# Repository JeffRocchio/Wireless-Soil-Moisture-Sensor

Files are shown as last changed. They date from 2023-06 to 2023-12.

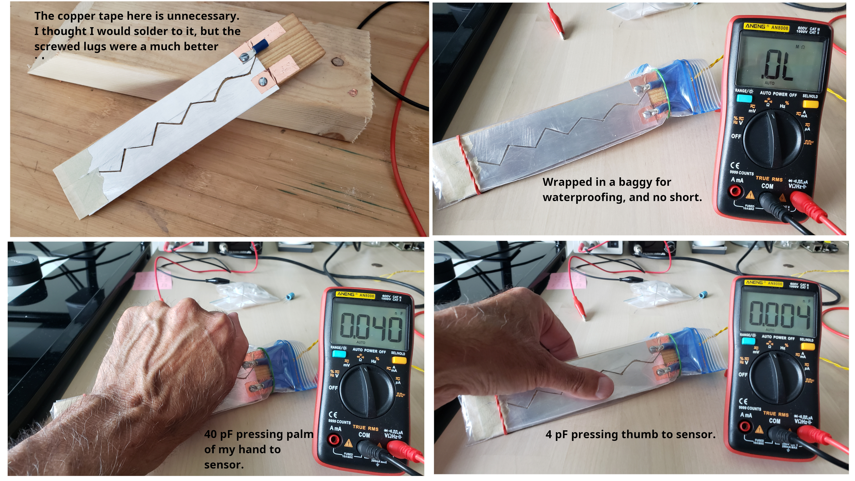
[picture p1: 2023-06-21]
ProjectLog/MS10_b_Sensor-design.jpg

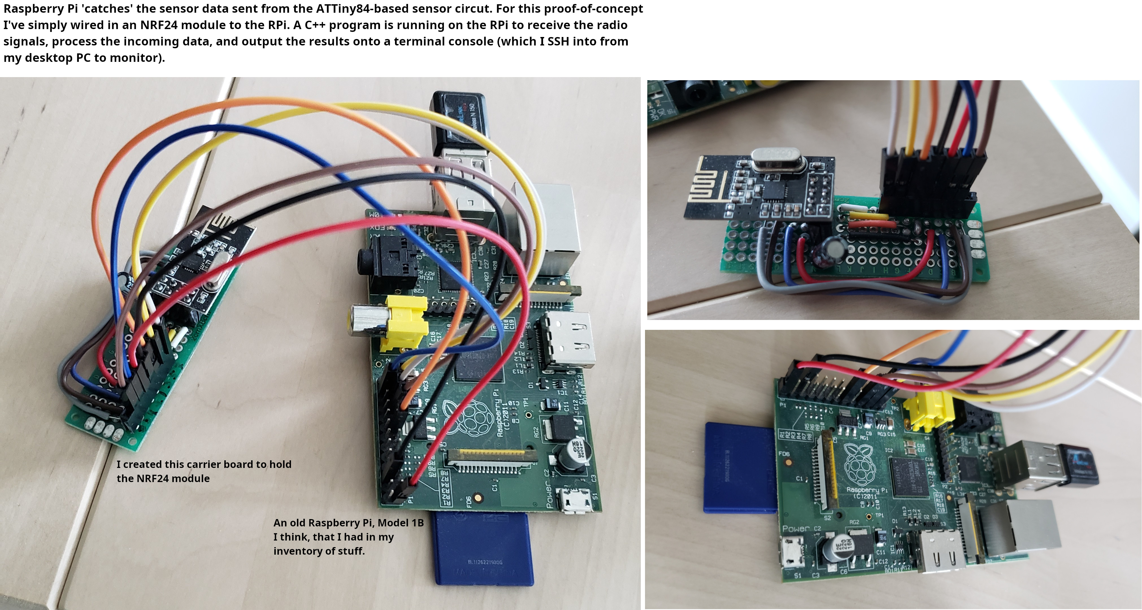
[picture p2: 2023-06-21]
Physical-Construction/ReceivingServer/Receiver-server_Raspberry-Pi-with-NRF24.jpg

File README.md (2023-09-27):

# Description

Wireless soil moisture sensor using capacitance as the sensing mechanism.

This is a DIY project for use in my own garden, and if it works out, my neighboorhood's community garden.

For the initial proof of concept I am making just one sensor device, which wirelessly sends its sensor data over to a Raspberry Pi for processing and display onto a terminal session (which I SSH into from my desktop PC). If the proof of concept works then I would have the Raspberry Pi post the data to a web page.

This project uses an ATTiny84 MCU and two NRF24 radio modules along with the Raspberry Pi.

The folder ProjectLog contains detailed notes on all the trials, tribulations, and successes as I go. Those log entries also contain key references - such as the Arduino core used for the ATTiny84 and the github repo for the NRF24 libraries.

# Status

**9/27/2023**: I have nearly completed work on *[Milestone #12](https://github.com/JeffRocchio/Wireless-Soil-Moisture-Sensor/blob/main/ProjectLog/MS12_a_Notes_Conversational-Software.pdf)*: Redesigning the ATTiny84 and Raspberry Pi software to be 'Event-Driven,' 'Non-Blocking,' and conversational. The only missing piece is the ability of the ATTiny to handle a command coming back from the RPi in one of it's ack packets. What I have done tho is implement a once every two hours logging function on the RPi so that I have a text file in the home directory of the RPi that I can CAT or TAIL via SSH to see the history of sensor readings. With this in place I will now deploy the sensor into an actual plant pot in my house and just see how it goes for awhile. My main interest at this point is to see if this capacitance approach to sensing soil moisture levels can actually be effective.

**July 2023**: I created a protocol of sorts for myself for managing test cases in the Arduino environment. This is documented in /home/`Software/tiny84/Readme-TESTcases.md`.

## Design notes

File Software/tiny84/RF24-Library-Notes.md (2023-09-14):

# nRF24 Arduino Library Notes

## Some Thoughts on the Use of Addresses:

I think when they're saying it's "best to think of addresses as a path," they mean that instead of a device transmitting its device ID (address), it is instead tagging it's outgoing transmission with the ID (address) of the recipient, ie the "path to the target." That's why the comment says: "0 uses address[0] transmit." It's not saying that I am device 0, it's saying: "This message is intended for the device whose address is zero." And I'm thinking the reason for this is for mesh network type situations where any node could receive a message and if that message is not intended for itself, per the address, then it would retransmit it forward so that after multiple hops it would finally reach its intended target - and that's the notion of a "path."

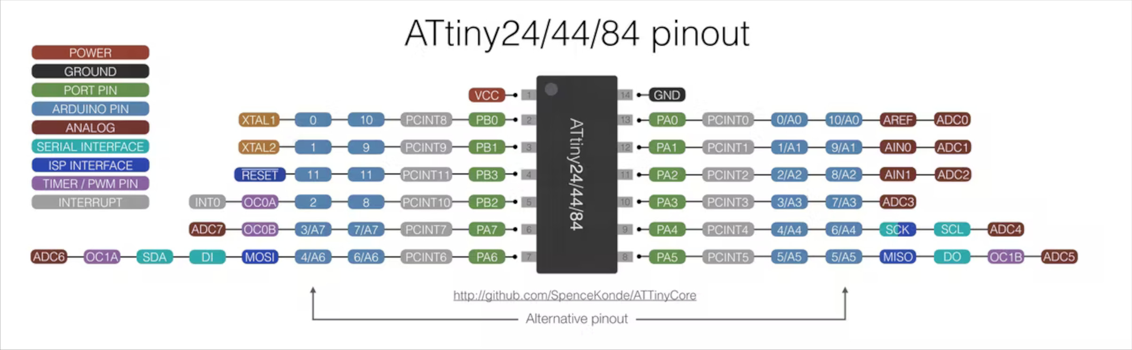
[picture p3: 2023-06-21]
Reference-and-Instructions/ATTiny84-Pinout-diagram.jpg

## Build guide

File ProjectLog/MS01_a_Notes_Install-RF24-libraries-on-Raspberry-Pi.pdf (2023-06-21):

# 1. Install or Update RF24 Libraries and Repo on Raspberry

Pi

@ https://github.com/nRF24/RF24/blob/master/docs/using_cmake.md#building-from-source-code

## Did this on 4/25/2022

Following the step-by-step instructions under the 'Build From Source' section (ignore the section above that about installing the package).

Uninstalled the prior-instlled rf24 .deb 'package:

pi@raspberrypi:/lib$ sudo dpkg -r rf24
(Reading database ... 45488 files and directories currently installed.) Removing rf24 (1.4.2) ...

And I then checked usr/libs, usr/include, usr/local/lib, and usr/local/include to be sure there were no artifacts left. There were none.

Proceeded to follow the 'Build from Source' instructions --

Step-1, I verified that cmake was already installed on my pi. Which it was.

Step-2, Make a directory to contain the RF24 library and possibly other RF24* libraries and enter it:

pi@raspberrypi:/home$ mkdir rf24libs
pi@raspberrypi:/home$ cd rf24libs

Step-3, Clone the RF24 repo and navigate to it:

pi@raspberrypi:/home/rf24libs$ git clone https://github.com/nRF24/RF24.git RF24 Cloning into 'RF24'...
remote: Enumerating objects: 7105, done.
remote: Counting objects: 100% (804/804), done.
remote: Compressing objects: 100% (252/252), done.
remote: Total 7105 (delta 668), reused 556 (delta 552), pack-reused 6301
Receiving objects: 100% (7105/7105), 8.48 MiB | 581.00 KiB/s, done.
Resolving deltas: 100% (4896/4896), done.

pi@raspberrypi:/home/rf24libs$ cd RF24 pi@raspberrypi:/home/rf24libs/RF24$

Step-4, Create a build directory inside the RF24 directory and navigate to it:

pi@raspberrypi:/home/rf24libs/RF24$ mkdir build pi@raspberrypi:/home/rf24libs/RF24$ cd build pi@raspberrypi:/home/rf24libs/RF24/build$

Step-5, Configure build environment:

pi@raspberrypi:/home/rf24libs/RF24/build$ cmake .. -D RF24_DRIVER=SPIDEV -- The C compiler identification is GNU 10.2.1
-- The CXX compiler identification is GNU 10.2.1
-- Detecting C compiler ABI info
-- Detecting C compiler ABI info - done
-- Check for working C compiler: /usr/bin/cc - skipped -- Detecting C compile features
-- Detecting C compile features - done
-- Detecting CXX compiler ABI info
-- Detecting CXX compiler ABI info - done
-- Check for working CXX compiler: /usr/bin/c++ - skipped -- Detecting CXX compile features
-- Detecting CXX compile features - done
-- Setting build type to 'Release' as none was specified. -- RF24 library version: 1.4.2
CMake Warning at cmake/Cache.cmake:27 (message):
ccache is enabled but was not found. Not using it
Call Stack (most recent call first): CMakeLists.txt:39 (include)

-- detected SoC: BCM2835
-- detected CPU type: armv6l
-- tool name being used: arm-linux-gnueabihf
-- Using driver: SPIDEV
-- linking to pigpio lib for interrupt functionality -- ready to package: librf24-SPIDEV_1.4.2-1_armhf.deb -- ready to package: librf24-SPIDEV-1.4.2-1.armhf.rpm -- Using utility library: /usr/lib/libpigpio.so
-- Configuring done
-- Generating done
-- Build files have been written to: /home/rf24libs/RF24/build pi@raspberrypi:/home/rf24libs/RF24/build$

Step-6, Build and install the library:

pi@raspberrypi:/home/rf24libs/RF24/build$ make

Scanning dependencies of target rf24
[ 16%] Building CXX object CMakeFiles/rf24.dir/RF24.cpp.o
[ 33%] Building CXX object CMakeFiles/rf24.dir/utility/SPIDEV/gpio.cpp.o
[ 50%] Building CXX object CMakeFiles/rf24.dir/utility/SPIDEV/spi.cpp.o
[ 66%] Building CXX object CMakeFiles/rf24.dir/utility/SPIDEV/compatibility.cpp.o [ 83%] Building CXX object CMakeFiles/rf24.dir/utility/SPIDEV/interrupt.cpp.o [100%] Linking CXX shared library librf24.so
[100%] Built target rf24
pi@raspberrypi:/home/rf24libs/RF24/build$ pi@raspberrypi:/home/rf24libs/RF24/build$ sudo make install [100%] Built target rf24
Install the project...
-- Install configuration: "Release"
-- Installing: /usr/local/include/RF24/utility/SPIDEV/includes.h
-- Installing: /usr/local/include/RF24/utility/SPIDEV/gpio.h
-- Installing: /usr/local/include/RF24/utility/SPIDEV/spi.h
-- Installing: /usr/local/include/RF24/utility/SPIDEV/compatibility.h -- Installing: /usr/local/include/RF24/utility/SPIDEV/RF24_arch_config.h -- Installing: /usr/local/include/RF24/utility/SPIDEV/interrupt.h
-- Installing: /usr/local/lib/librf24.so.1.4.2
-- Installing: /usr/local/lib/librf24.so.1
-- Installing: /usr/local/lib/librf24.so
-- Installing: /usr/local/include/RF24/RF24.h
-- Installing: /usr/local/include/RF24/nRF24L01.h
-- Installing: /usr/local/include/RF24/printf.h
-- Installing: /usr/local/include/RF24/RF24_config.h
-- Installing: /usr/local/include/RF24/utility/includes.h -- Updating ldconfig
pi@raspberrypi:/home/rf24libs/RF24/build$

Step-7, Build the examples:

pi@raspberrypi:/home/rf24libs/RF24/build$ cd ../examples_linux pi@raspberrypi:/home/rf24libs/RF24/examples_linux$

pi@raspberrypi:/home/rf24libs/RF24/examples_linux/build$ cmake .. -D RF24_DRIVER=SPIDEV
-- detected SoC: BCM2835
-- detected CPU type: armv6l
-- tool name being used: arm-linux-gnueabihf
-- Using driver: SPIDEV
-- using RF24 library: /usr/local/lib/librf24.so
-- Configuring done
-- Generating done
-- Build files have been written to: /home/rf24libs/RF24/examples_linux/build pi@raspberrypi:/home/rf24libs/RF24/examples_linux/build$ make Scanning dependencies of target scanner
[ 7%] Building CXX object CMakeFiles/scanner.dir/scanner.cpp.o [ 14%] Linking CXX executable scanner
[ 14%] Built target scanner
Scanning dependencies of target multiceiverDemo
[ 21%] Building CXX object CMakeFiles/multiceiverDemo.dir/multiceiverDemo.cpp.o [ 28%] Linking CXX executable multiceiverDemo
[ 28%] Built target multiceiverDemo
Scanning dependencies of target interruptConfigure
[ 35%] Building CXX object CMakeFiles/interruptConfigure.dir /interruptConfigure.cpp.o
[ 42%] Linking CXX executable interruptConfigure
[ 42%] Built target interruptConfigure
Scanning dependencies of target manualAcknowledgements
[ 50%] Building CXX object CMakeFiles/manualAcknowledgements.dir /manualAcknowledgements.cpp.o
[ 57%] Linking CXX executable manualAcknowledgements
[ 57%] Built target manualAcknowledgements
Scanning dependencies of target acknowledgementPayloads
[ 64%] Building CXX object CMakeFiles/acknowledgementPayloads.dir /acknowledgementPayloads.cpp.o
[ 71%] Linking CXX executable acknowledgementPayloads
[ 71%] Built target acknowledgementPayloads
Scanning dependencies of target streamingData
[ 78%] Building CXX object CMakeFiles/streamingData.dir/streamingData.cpp.o [ 85%] Linking CXX executable streamingData
[ 85%] Built target streamingData
Scanning dependencies of target gettingstarted
[ 92%] Building CXX object CMakeFiles/gettingstarted.dir/gettingstarted.cpp.o [100%] Linking CXX executable gettingstarted
[100%] Built target gettingstarted pi@raspberrypi:/home/rf24libs/RF24/examples_linux/build$

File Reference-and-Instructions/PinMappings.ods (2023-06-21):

Moisture Sensor Project
NRF24 to ATTiny84 Pin Mapping
 | Signal | NRF24 | ATTiny84 | Wire Color
 | GND | 1 | 14 | Black
 | VCC – 3.3 V | 2 | 1 | Red
 | CE | 3 | 11 | Yellow
 | CSN | 4 | 10 | Blue
 | SCK | 5 | 9 | Green
 | MOSI | 6 | 8 | Grey
 | MISO | 7 | 7 | White
 | IRQ | 8 | NA
 | Sources:
 | NRF24 module to ATtiny24/44/84 Pin map. Lower down on page @ https://rf24.readthedocs.io/en/latest/md_docs_attiny.html.
 | NRF24 Module Pinout Diagram @ https://github.com/nRF24/RF24/blob/master/images/pinout.jpg

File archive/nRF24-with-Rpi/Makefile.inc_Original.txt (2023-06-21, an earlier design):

Contents of Makefile.inc from the original install --

OS=LINUX
SOC=BCM2835
DRIVER=RPi
CPUFLAGS=-marm -march=armv6zk -mtune=arm1176jzf-s -mfpu=vfp -mfloat-abi=hard
CFLAGS=-marm -march=armv6zk -mtune=arm1176jzf-s -mfpu=vfp -mfloat-abi=hard -Ofast -Wall -pthread
PREFIX=/usr/local
REMOTE_PREFIX=/usr/local
LIB=rf24
LIBNAME=librf24.so.1.4.2
LIB_VERSION=1.4.2
LIBSYMLINKS=librf24.so.1.4 librf24.so.1 librf24.so
LIBDEPRECATE=librf24-bcm.so
CC=arm-linux-gnueabihf-gcc
CXX=arm-linux-gnueabihf-g++
LIB_DIR=/usr/local/lib
REMOTE_LIB_DIR=/usr/local/lib
HEADER_DIR=/usr/local/include/RF24
REMOTE_HEADER_DIR=/usr/local/include/RF24
DRIVER_DIR=utility/RPi
ARCH_DIR=utility
SHARED_LINKER_FLAGS= -shared -Wl,-soname,librf24.so.1
LDCONFIG=ldconfig
REMOTE_LDCONFIG=/sbin/ldconfig
EXAMPLES_DIR=/usr/local/bin
REMOTE_EXAMPLES_DIR=/usr/local/bin

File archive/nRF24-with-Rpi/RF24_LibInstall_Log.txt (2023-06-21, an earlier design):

3/25/2002 at 5:30pm

Below is the terminal output resulting from running the
install.sh script I downloaded from
https://github.com/nRF24/RF24/blob/master/docs/linux_install.md

(To get install.sh onto my Pi using my SSH shell, I had to execute:
(pi@raspberrypi:~/myRF24 $ curl https://raw.githubusercontent.com/nRF24/.github/main/installer/install.sh > install.sh
(For some unknown reason trying to use wget didn't work - wget just kept timing out. I tried wget on my
(desktop PC and worked just fine. And could do a ping to that domain on the Pi and that worked just fine;
(I could even wget a tiny file at google and that worked fine. But this install.sh file just kept
timing out.)

==========================================================================================================================

pi@raspberrypi:~/myRF24 $ ./install.sh

RF24 libraries installer by TMRh20 and 2bndy5
report issues at https://github.com/nRF24/RF24/issues

******************** NOTICE **********************
This installer will create a 'rf24libs' folder for installation of selected libraries
To prevent mistaken deletion, users must manually delete existing library folders within 'rf24libs' if upgrading
Run 'sudo rm -r rf24libs' to clear the entire directory

Creating rf24libs folder.
Installing cmake from apt-get
Reading package lists... Done
Building dependency tree... Done
Reading state information... Done
The following additional packages will be installed:
  cmake-data libarchive13 libjsoncpp24 librhash0
Suggested packages:
  cmake-doc ninja-build lrzip
The following NEW packages will be installed:
  cmake cmake-data libarchive13 libjsoncpp24 librhash0
0 upgraded, 5 newly installed, 0 to remove and 0 not upgraded.
Need to get 5,335 kB of archives.
After this operation, 28.7 MB of additional disk space will be used.
Do you want to continue? [Y/n] Y
Get:1 http://archive.raspberrypi.org/debian bullseye/main armhf cmake-data all 3.18.4-2+rpt1+rpi1 [1,726 kB]
Get:2 http://mirror.pit.teraswitch.com/raspbian/raspbian bullseye/main armhf libarchive13 armhf 3.4.3-2 [294 kB]
Get:5 http://archive.raspberrypi.org/debian bullseye/main armhf cmake armhf 3.18.4-2+rpt1+rpi1 [3,108 kB]
Get:3 http://mirror.pit.teraswitch.com/raspbian/raspbian bullseye/main armhf libjsoncpp24 armhf 1.9.4-4 [67.0 kB]
Get:4 http://mirror.pit.teraswitch.com/raspbian/raspbian bullseye/main armhf librhash0 armhf 1.4.1-2 [141 kB]
Fetched 5,335 kB in 3s (1,691 kB/s)
Selecting previously unselected package cmake-data.
(Reading database ... 42529 files and directories currently installed.)
Preparing to unpack .../cmake-data_3.18.4-2+rpt1+rpi1_all.deb ...
Unpacking cmake-data (3.18.4-2+rpt1+rpi1) ...
Selecting previously unselected package libarchive13:armhf.
Preparing to unpack .../libarchive13_3.4.3-2_armhf.deb ...
Unpacking libarchive13:armhf (3.4.3-2) ...
Selecting previously unselected package libjsoncpp24:armhf.
Preparing to unpack .../libjsoncpp24_1.9.4-4_armhf.deb ...
Unpacking libjsoncpp24:armhf (1.9.4-4) ...
Selecting previously unselected package librhash0:armhf.
Preparing to unpack .../librhash0_1.4.1-2_armhf.deb ...
Unpacking librhash0:armhf (1.4.1-2) ...
Selecting previously unselected package cmake.
Preparing to unpack .../cmake_3.18.4-2+rpt1+rpi1_armhf.deb ...
Unpacking cmake (3.18.4-2+rpt1+rpi1) ...
Setting up libarchive13:armhf (3.4.3-2) ...
Setting up libjsoncpp24:armhf (1.9.4-4) ...
Setting up librhash0:armhf (1.4.1-2) ...
Setting up cmake-data (3.18.4-2+rpt1+rpi1) ...
Setting up cmake (3.18.4-2+rpt1+rpi1) ...
Processing triggers for man-db (2.9.4-2) ...
Processing triggers for libc-bin (2.31-13+rpt2+rpi1+deb11u2) ...
Do you want to install the RF24 library, [y/N]? Y
Do you want to install the RF24Network library, [y/N]?
Do you want to install the RF24Mesh library, [y/N]?
Do you want to install the RF24Gateway library, [y/N]?
WARNING: It is advised to remove the previously installed RF24 library first.
        This is done to avoid Runtime conflicts.
*** Which hardware driver library do you wish to use? ***
1. BCM2835 Driver (aka RPi)
2. SPIDEV (most compatible, Default)
3. WiringPi (support deprecated)
4. MRAA (Intel Devices)
5. PiGPIO
6. LittleWire
2

Installing RF24 Repo...
Cloning into 'rf24libs/RF24'...
remote: Enumerating objects: 8814, done.
remote: Counting objects: 100% (4574/4574), done.
remote: Compressing objects: 100% (1285/1285), done.
remote: Total 8814 (delta 3376), reused 4319 (delta 3259), pack-reused 4240
Receiving objects: 100% (8814/8814), 8.97 MiB | 756.00 KiB/s, done.
Resolving deltas: 100% (5925/5925), done.

Already on 'master'
Your branch is up to date with 'origin/master'.
-- The C compiler identification is GNU 10.2.1
-- The CXX compiler identification is GNU 10.2.1
-- Detecting C compiler ABI info
-- Detecting C compiler ABI info - done
-- Check for working C compiler: /usr/bin/cc - skipped
-- Detecting C compile features
-- Detecting C compile features - done
-- Detecting CXX compiler ABI info
-- Detecting CXX compiler ABI info - done
-- Check for working CXX compiler: /usr/bin/c++ - skipped
-- Detecting CXX compile features
-- Detecting CXX compile features - done
-- Setting build type to 'Release' as none was specified.
-- RF24 library version: 1.4.2
CMake Warning at cmake/Cache.cmake:27 (message):
  ccache is enabled but was not found.  Not using it
Call Stack (most recent call first):
  CMakeLists.txt:39 (include)

-- detected SoC: BCM2835
-- detected CPU type: armv6l
-- tool name being used: arm-linux-gnueabihf
-- RF24_DRIVER (set from env var) = SPIDEV
-- Using driver: SPIDEV
-- ready to package: librf24-SPIDEV_1.4.2-1_armhf.deb
-- ready to package: librf24-SPIDEV-1.4.2-1.armhf.rpm
-- Disabling IRQ pin support
-- Configuring done
-- Generating done
-- Build files have been written to: /home/pi/rf24libs/RF24/build
Scanning dependencies of target rf24
[ 20%] Building CXX object CMakeFiles/rf24.dir/RF24.cpp.o
[ 40%] Building CXX object CMakeFiles/rf24.dir/utility/SPIDEV/gpio.cpp.o
[ 60%] Building CXX object CMakeFiles/rf24.dir/utility/SPIDEV/spi.cpp.o
[ 80%] Building CXX object CMakeFiles/rf24.dir/utility/SPIDEV/compatibility.cpp.o
[100%] Linking CXX shared library librf24.so
[100%] Built target rf24
[100%] Built target rf24
Install the project...
-- Install configuration: "Release"
-- Installing: /usr/local/include/RF24/utility/SPIDEV/includes.h
-- Installing: /usr/local/include/RF24/utility/SPIDEV/gpio.h
-- Installing: /usr/local/include/RF24/utility/SPIDEV/spi.h
-- Installing: /usr/local/include/RF24/utility/SPIDEV/compatibility.h
-- Installing: /usr/local/include/RF24/utility/SPIDEV/RF24_arch_config.h
-- Installing: /usr/local/lib/librf24.so.1.4.2
-- Installing: /usr/local/lib/librf24.so.1
-- Installing: /usr/local/lib/librf24.so
-- Installing: /usr/local/include/RF24/RF24.h
-- Installing: /usr/local/include/RF24/nRF24L01.h
-- Installing: /usr/local/include/RF24/printf.h
-- Installing: /usr/local/include/RF24/RF24_config.h
-- Installing: /usr/local/include/RF24/utility/includes.h
-- Updating ldconfig

Do you want to build the RF24 examples [Y/n]? Y
-- The CXX compiler identification is GNU 10.2.1
-- Detecting CXX compiler ABI info
-- Detecting CXX compiler ABI info - done
-- Check for working CXX compiler: /usr/bin/c++ - skipped
-- Detecting CXX compile features
-- Detecting CXX compile features - done
-- detected SoC: BCM2835
-- detected CPU type: armv6l
-- tool name being used: arm-linux-gnueabihf
-- RF24_DRIVER (set from env var) = SPIDEV
-- Using driver: SPIDEV
-- using RF24 library: /usr/local/lib/librf24.so
-- Skipping interruptConfigure.cpp example as it is incompatible with selected driver library
-- Configuring done
-- Generating done
-- Build files have been written to: /home/pi/rf24libs/RF24/examples_linux/build
Scanning dependencies of target scanner
[  8%] Building CXX object CMakeFiles/scanner.dir/scanner.cpp.o
[ 16%] Linking CXX executable scanner
[ 16%] Built target scanner
Scanning dependencies of target multiceiverDemo
[ 25%] Building CXX object CMakeFiles/multiceiverDemo.dir/multiceiverDemo.cpp.o
[ 33%] Linking CXX executable multiceiverDemo
[ 33%] Built target multiceiverDemo
Scanning dependencies of target manualAcknowledgements
[ 41%] Building CXX object CMakeFiles/manualAcknowledgements.dir/manualAcknowledgements.cpp.o
[ 50%] Linking CXX executable manualAcknowledgements
[ 50%] Built target manualAcknowledgements
Scanning dependencies of target acknowledgementPayloads
[ 58%] Building CXX object CMakeFiles/acknowledgementPayloads.dir/acknowledgementPayloads.cpp.o
[ 66%] Linking CXX executable acknowledgementPayloads
[ 66%] Built target acknowledgementPayloads
Scanning dependencies of target streamingData
[ 75%] Building CXX object CMakeFiles/streamingData.dir/streamingData.cpp.o
[ 83%] Linking CXX executable streamingData
[ 83%] Built target streamingData
Scanning dependencies of target gettingstarted
[ 91%] Building CXX object CMakeFiles/gettingstarted.dir/gettingstarted.cpp.o
[100%] Linking CXX executable gettingstarted
[100%] Built target gettingstarted

Complete! To run the example:
cd ~/rf24libs/RF24/examples_linux/build
sudo ./gettingstarted
Would you like to install the unified python wrapper package (pyrf24) [y/N]?

*** Installer Complete ***
See http://tmrh20.github.io for documentation
See http://tmrh20.blogspot.com for info

Listing repositories in ~/rf24libs
RF24
pi@raspberrypi:~/myRF24 $

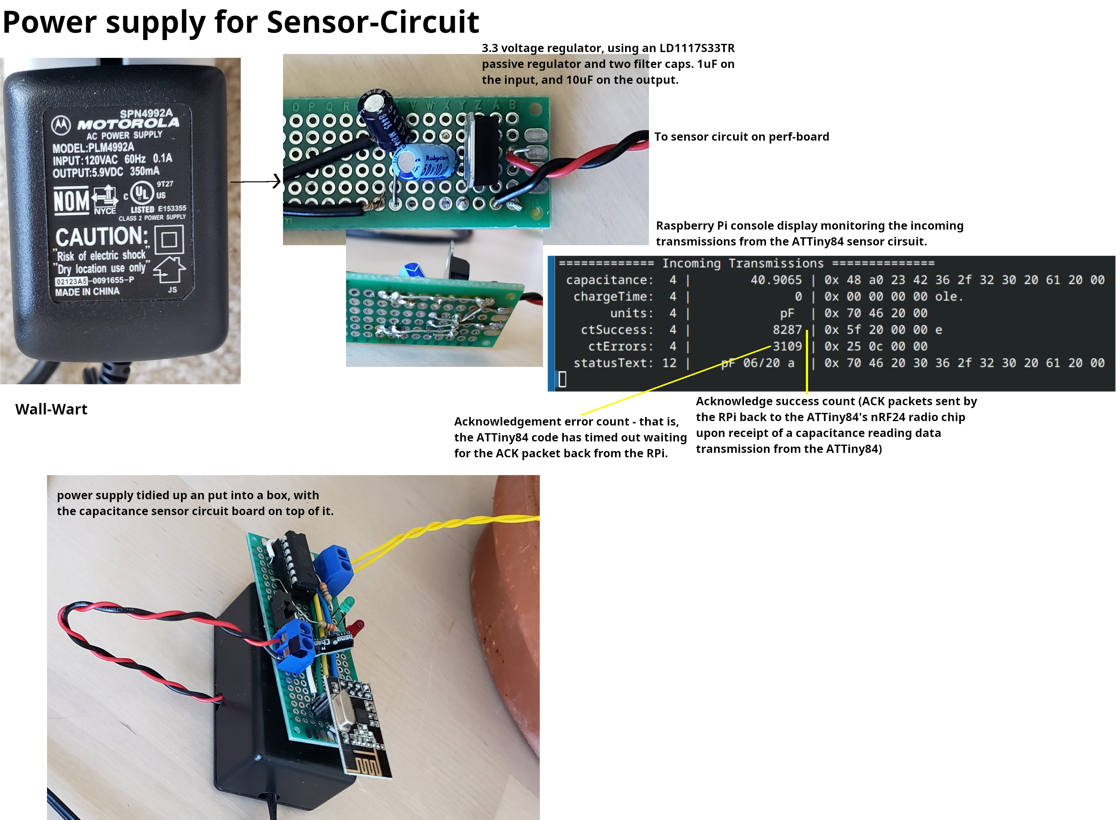
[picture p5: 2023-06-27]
Physical-Construction/Sensor/SensorCircuit_PowerSupply.jpg

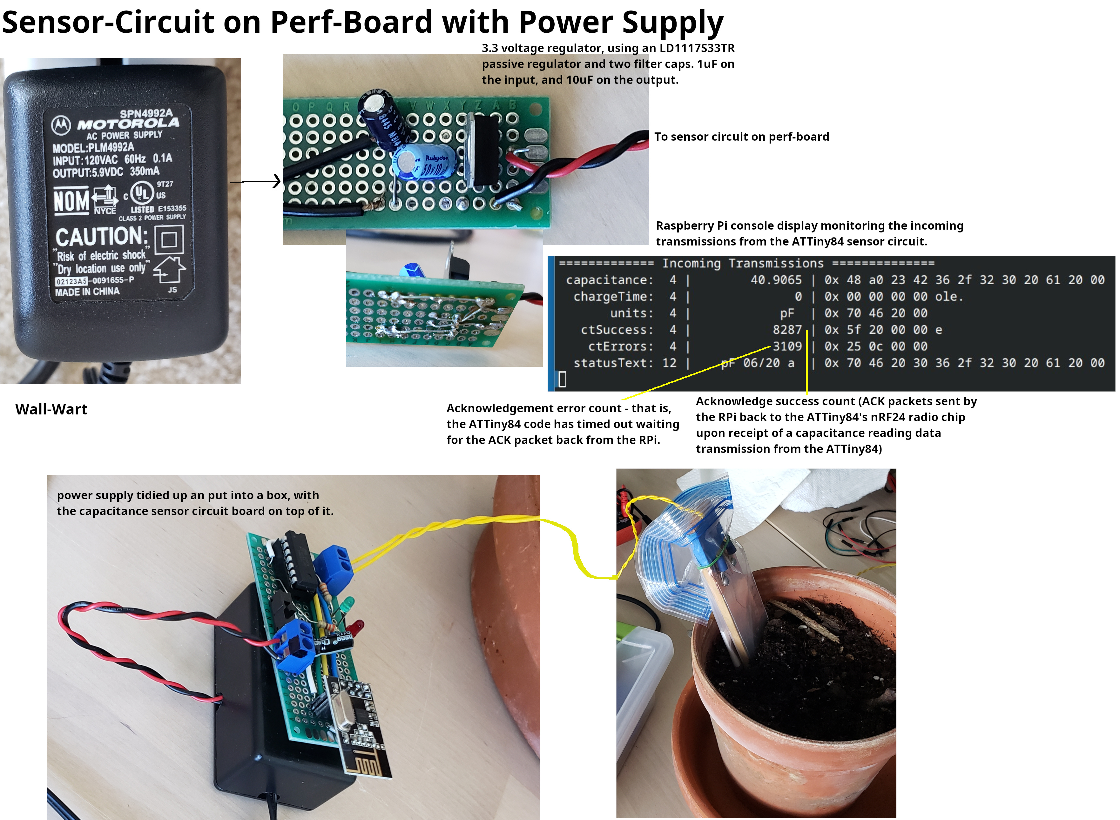
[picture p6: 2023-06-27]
Physical-Construction/Sensor/Sensor-circuit-with-Power-supply.jpg

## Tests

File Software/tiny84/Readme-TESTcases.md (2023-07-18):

Notes on Testing
========================================

I haven't been able to work out a 'clean' way to use test cases in the Arduino environment due to the way that the IDE and the environment is dependent upon the root sketch file name being the exact same as the directory name; and that you cannot specify file-paths in the #include statements. So for myself I've defined the following procedure for test-cases:

   * Each test case gets it's own subdirectory, inside the main sketch directory. In that directory is the test case sketch and any files it depends on that are not library files in the normal Arduino library directory.

   * These subdirectories are named 'TC##_DescriptiveName' where the ## is the ID number of the test case and 'DescriptiveName' is a brief title for the test case.

The procedure to work on, and run, a test case is as follows:

   1. Do a git commit just before starting in on the below procedure. This way you have a way to roll back to this point should things get out of hand as you muck around with the code in various files trying to get the test case to work out. Use command: [`git commit -m "TC##_DescriptiveName. Commit just prior to initiating work on test case."`]

   1. IF starting a new test case, create the directory for it, using the above noted naming convention.

   1. COPY all files the test case depends on into the test case's subdirectory. Do this as a COPY and not a move just so you have a handy copy in the parent directory to revert back to if need be.

   1. IF starting a new test case, create a .ino file that will be the main sketch that will perform the test(s) of your test case. Typically the easiest way to do this is to copy the main sketch from a prior test case that will serve as a good starting basis for your new test case. Copy such a sketch from it's TC## subdirectory into the subdirectory of the test case you are using.

   1. Open your TC##_DescriptiveName.ino sketch in the Arduino IDE.

   1. Write your test code.

   1. PERFORM TESTS, COMMIT AS APPROPRIATE. Make changes and bug fixes as needed until you are done with the test case. Consider making git commits as you go, based on the extent and nature of code modifications you are making to satisfy the test case; esp changes to the dependent files that will get applied back up to the primary sketch once the test case work is completed. Think of these as snapshots you can use to recover back to in case you end up in dead-ends and need to restart. Use: [`git commit -m "TC##_DescriptiveName. WIP. [optional brief description.]"`]

   1. PRE-CLOSE COMMIT. Once you have completed the test case, capture a snapshot for a reliable rollback point. Do: [`git commit -m "TC##_DescriptiveName. Work completed, pre-close commit."`]

   1. COPY all main-sketch dependent files back up to the parent directory. Do not copy the test case's main sketch nor files that are only used by the test case's main sketch. Obviously some of those files will have been modified as the test was run and fixes made. So you are bringing those changes back up to the ATTiny84 sensor program you are building or modifying. Therefore, as you make this file copy you will be asked if you wish to overwrite the pre-existing files. Just respond 'yes' to all. This will, of course, also overwrite files that you didn't need to change as part of your test work, but that's fine. I feel it's more reliable to just overwrite all the files rather than working out which files changed as you tested and which did not.

   1. CLOSE TEST CASE: Do: [`git commit -m "TC##_DescriptiveName: Tests Completed. Dependent files [have | have not] been modified."`] In conjunction with the above mentioned commits this gives you several good rollback points just in case something bad or mysterious has happened. You can get back to the state of the code at several key points to work out issues or mysteries.

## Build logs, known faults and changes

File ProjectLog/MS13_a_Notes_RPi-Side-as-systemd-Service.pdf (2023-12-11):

# 13. RPi Side as systemd Service

NOTE - December 11, 2023: I am continuing with this project pushed down onto my stack (so-to-speak) in order to give my time to several other projects and activities that have fallen a bit to far by the wayside. Do not yet have a sense of when I'll return back to this project. But in order to have the sensor running 'in the field,' in an actual flower pot, I feel the need to have the RPi side application autostart at reboot time. So I have take some time to add this feature.

Purpose: Make the RPi application, RPi_CapDataReceive, into a systemd Service that starts at reboot.

Goal: Create a systemd unit file. Make any needed mods to the RPi_CapDataReceive.cpp code to support running as an autostart background service.

Design Notes:
Considerations:
1. Absolute minimal change to the code.
2. Might want to consider writing a log file for error/debug info as I won't have a terminal screen available to be able to see any program output. NOTE: I elected not to do this as, instead, I modified the program to write good system log entries which I can inspect with journalctl.

Key References --
systemd Service Instructional References --https://linuxhandbook.com/create-systemd-services/https://www.tecmint.com/create-systemd-service-linux/

Raspberry Pi Login --
Pi user is: pi. So SSH login is:

password to the pi is:
NOTE: I have created an alias command in my .bash_profile for the login: ' | '
To see user custom services:

And then once in, get into the working directory for the nRF24 utilities and programs:

The run the RPi receiving program:
./RPi_CapDataReceive
Good reference for running the process detached from terminal: https://linuxconfig.org/detach-process-program-from-current-shell-to-keep-it-alive-after-logout (https://linuxconfig.org/detach-process-program-from-current-shell-to-keep-it-alive-after-logout)
Based on this, the command to run in an SSH terminal to keep the RPi programming forever, even after detaching the SSH session, is:

Working with Service --
To see user custom services:
To modify the service file follow these steps:

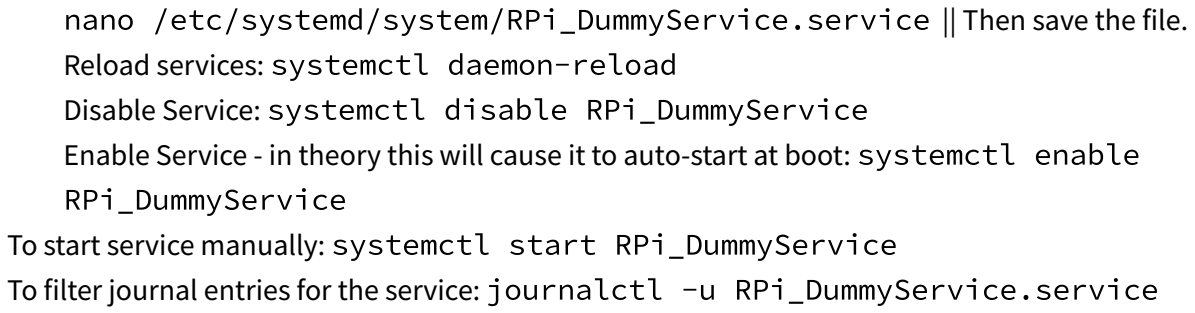
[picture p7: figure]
|| Then save the file.; Reload services:; Disable Service:; To start service manually:

Enable Service - in theory this will cause it to auto-start at boot:

To filter journal entries for the service:

To Modify RPi side .cpp code --
Use Kate on my desktop.
Then copy to the RPi using below command:

scp /home/jroc/Dropbox/projects/MoistureSensor/Software/RPi/RPi_CapDataReceive.cpp pi@[ip-address-of-

the-RPi-on-my-LAN]:/home/rf24libs/RF24/examples_linux/
NOTE: My bash alias command for the above is: ' | '
Then on the RPi, cd into the build directory and execute 'make'
BUT if this is the first iteration of the program, you need to first add it to CMakeLists.txt in the examples_linux directory (above the build directory).
NOTE: All the code is under git version control. So the executables for both the ATTiny and RPi are on my desktop.
GitHub Repo: https://github.com/JeffRocchio/Wireless-Soil-Moisture-Sensor

Next Step: Fabricate a few different capacitor sensors to test.

12/11/2023 --
Results: Success in having RPi-CapDataReceive auto-run on the Raspberry Pi boot-up as a systemd service.
Changes from 12/08:
Modified | so it's console output makes better sense in the
system journal as a service. Also added a parameter switch, "-v," for 'verbose' output which a user could use when invoking the program from a terminal to get the same verbose and realtime output as prior releases.

1.

Created a systemd service file:

2.

3. Enabled the above service file to run at boot.

ATTiny Code: No changes made to this code today.
RPi Code: | . Made mods so that it writes nice journalctl log entries.
Added the -v parameter to obtain the old verbose output onto a terminal screen, if desired, when manually run from an open terminal window.
Raspberry Pi Config: Created systemd unit file:
Git: Commit Description: MS13, 2023-12-11: RPi_CapDataReceivesystemd service running on RPi, autostart at bootup. SUCCESS - COMPLETE.
Next Steps: None for this milestone - Milestone complete.

12/08/2023 --
Results: Success in getting a dummy service to auto-run on the Raspberry Pi boot-up.
I created a simple CPP program to act as a dummy service. Wanted to do this before trying to configure the main RPi sensor data capture program as a service so that I could work out the details of how best to do this.

So this proof-of-concept is a success. Now I can modify my sensor-server code accordingly to run as a boot-up service.

Changes from 12/07:

ATTiny Code: No changes made to this code today.

RPi Code: | . Made mods so that how it writes to it's own log file and the
journalctl log is more sensible.

Installed the RPi_DummyService.service file as a root system service by placing it in .

1.

2. Set the After target to multi-user.target; same for WantedBy in the [Install] section.
3. 'enable'd the service.
4. Rebooted the PI.
RPi_DummyService ran just fine; and exited with success. And this includes both writing
to my specific log file | and the ' | ' lines in my code also
wrote very nicely into the journalctl system log such that I could execute
and see the entries for the services being started up, my 'cout' strings, and systemd telling me the service completed successfully.

5.

Modified | so it's console output makes better sense in the
system journal.

1.

Moved the service file from
TO
. (Thus removing it from /home/pi/.config/systemd/user).

2.

3. sudo enable'd the now root system service.

journalctl log is more sensible.

Raspberry Pi Config: Created systemd unit file:

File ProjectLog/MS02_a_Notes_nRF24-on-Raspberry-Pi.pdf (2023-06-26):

# 02. nRF24 on Raspberry Pi

Captain's Log

Pi user is: pi

SSH login is: ssh pi@192.168.1.118

password: pi9012

Key Reference:

What I finally discovered on 3/25 is the below site is the key resource for the nRF24:

nRF24 / RF24 github repo @ https://github.com/nRF24/RF24

And then the documentation that goes with the above github repo:

https://rf24.readthedocs.io/en/latest/

Introduction --

After much research and confusion I have decided to try to get an nRF24 chip working on one of my old Raspberry Pi's. This is a P1 (2011). I have seen some references to doing that as I was researching the ATTiny approaches. Since I got so confused and boloxed up trying to start out with the ATTiny 84 I figured this might be an easier way to get started. Also, I figure that with the richer environment of the Pi I'd be able to use it ongoing to monitor the nRF24 emissions as I work through experiments and issues with the ATTiny platform. And, finally, at the end of the day I expect to use a Pi as the data-catching server in my house that will catch the data from the garden and then post it to the web site on the internet.

So - here's my log of trying to get this to work.

4/4/2022 --

"First Light!," so-to-speak. Today I wired up the RPi to the little nRF24 carrier board I made; booted up the Pi; opened the SSH terminal window into the Pi; and fired up the scanner 'example' program. Amazingly enough, it is working - showing data on some of the channels - which I assume are my home's WiFi channels in the 2.4 GHz band. I wired it up using the reference as noted in the Key Reference section above. That is:

RF24 | Pi pin | Function
1 | 25 | GND
2 | 17 | VCC

3 | 15 | CE
4 | 24 | CSN
5 | 23 | SCK
6 | 19 | MOSI
7 | 21 | MISO
8 | (unused)

See file: Dropbox/projects/MoistureSensor/nRF24-with-Rpi/FirstLight_04-04-2022.txt to see the terminal output from the running scanner program.

So now I think I should make a change or two to the scanner.cpp program to see if I can wrap my head around the radio code and how to control it.

3/25/2022 (b) --

The below, 3/25/2022 (a) activities, created a mass of confusion in my mind. Esp as I was unable to compile the example receiver program. It couldn't find any rf24 libraries. And I couldn't work out what was going on. Plus the comments section seemed to imply there were any number of errors and faults with repo/code at that 'Key Reference' site I was using.

So...more googling about. I came across this refererence; which gives me confidence because the dates of last updates and pull requests are current, not 8 years old like so many others. So now I'm going down the path as this github repo:

RF24/docs/linux_install.md @ https://github.com/nRF24/RF24/blob/master/docs/linux_install.md

5:54pm: OK, so I am following the step-by-step instructions at the above '.../linux_install.md' page. The Pi is now doing all sorts of downloading and install stuff. I took all the defaults for the various options it presented to me. It installed with no errors. Here is what it presented me in the end:

Complete! To run the example:
cd ~/rf24libs/RF24/examples_linux/build
sudo ./gettingstarted
Would you like to install the unified python wrapper package (pyrf24) [y/N]?

*** Installer Complete ***
See http://tmrh20.github.io for documentation
See http://tmrh20.blogspot.com for info

Listing repositories in ~/rf24libs
RF24

For the complete transcript of the terminal output, see: /home/jroc/Dropbox/projects/MoistureSensor/nRF24-with-Rpi/RF24_LibInstall_Log.txt

I had to do a /home/pi/rf24libs/RF24/examples_linux/build/scanner command to find the compiled scanner executable. (I could see from the install.sh terminal output that it did compile it.) So I did find it at /home/pi /rf24libs/RF24/examples_linux/build/scanner. So then I executed:

cd /home/pi/rf24libs/RF24/examples_linux/build/scanner

./scanner

And 'scanner' is running!! Finally I feel I'm getting somewhere.

OK, time to wire the nRF24 module to the Pi. Note that the install readme page states this:

Edit the gettingstarted example, to set your pin configuration

nano gettingstarted.cpp
make
sudo ./gettingstarted

3/25/2022 (a) --

Today's Key Reference: Connecting an nRF24L01+ to Raspberry Pi @ https://www.hackster.io/wirekraken/connecting-an-nrf24l01-to-raspberry-pi-9c0a57 (https://www.hackster.io/wirekraken/connecting-an-nrf24l01-to-raspberry-pi-9c0a57)

Ok, interesting to study the git repo from the above reference. So apparently much / most? of the code is actually using the same source as the Arduino and ATTiny examples I have been looking at. The nRF24 library contains pragma defs to tell the source what architecture you are compiling for. So this 'wirekraken' guy took the original nRF24 source, set the defs for 'Linux,' and then built some examples to run on the pi.

Importantly, he also created the 'scanner' executable program. Which, apparently, is complied to run on the Pi. So, in principle, it can simply be downloaded and run.

But I am going to git clone the entire repo, per his sequence of steps in his instructable. Tho first I have to install git on the pi.

1. First make sure the pi is all up to date. Execute:

sudo apt full-upgrade

This took quite awhile. About 30 minutes I'd say.

Then: sudo reboot

2. Make a directory to clone into and CD into. Execute:

mkdir nrf1
cd nrf1
3. Now install git. Execute:

sudo apt install git

Reference @ https://linuxize.com/post/how-to-install-git-on-raspberry-pi/

4. Clone the repo. Execute:

git clone https://github.com/wirekraken/Raspberry-Pi-NRF24.git xxx

Turns out this command created a new subdirectory, called Raspberry-Pi-NRF24. So I shouldn't have done #2 above. Or better, I should specified which directory I wanted to use so that I could have had my intended simple to type directory name.

5. Attempt to run the scanner program. Execute:

sudo ./scanner

For some reason I don't understand, you do have use that "./" syntax in front of the program for it to be executed.

Running it, with no radio chip yet wired in, I get the same error many others have reported. Namely: ./scanner: error while loading shared libraries: librf24.so.1: cannot open shared object file: No such file or directory . If I am reading the comments about this correctly, you do have to have radio wired in to not get that error.

For hardware connections - Key Reference: web page with the pi's pinout reference, which I'll need in order to hook up the nRF24 chip to the pi. See "Raspberry gPIo" @ https://learn.sparkfun.com/tutorials/raspberry-gpio/gpio-pinout

And this is also useful: @ https://docs.google.com/document/d/1aZ2xJYndN81k93rzOXoILpIjogRsWb3JwEnGnfbqTXE/edit (https://docs.google.com/document/d/1aZ2xJYndN81k93rzOXoILpIjogRsWb3JwEnGnfbqTXE/edit)

3/24/2022 --

The attempt to get my pi up and running on 3/22 didn't work. First, trying to use an adapter to connect the screen to one of my big Dell screens didn't work. The Dell screen never saw a 'signal.' Going downstairs and connecting to the TV via HDMI did work to show the raspberry pi OS's desktop; but I was never able to get WiFi working. After *much* mucking about I found an article about running the pi OS 'headless.' There is a way to do that such that you can use the graphical UI on the pi from a window on a seperate PC, using a special app on your PC for this - so-called 'VNC.' However, I elected to reburn my SD card with the 'Lite' version of pi OS - this is the Linux OS without any desktop. With this version you SSH into the pi from any terminal running on any PC in your network.

Also of note - in making that 2nd SD card image I found that the raspberry pi 'Imager' app was available in the fedora repository, so I installed that app onto the white laptop and used that to burn the SD card. This is much easier than the manual method I used on 3/22. Definitely go this way in future.

To create the SD card with the OS on it and SSH into it; and/or run the UI remotely: "How to setup your Raspberry Pi, Headless!" @ https://www.hackster.io/435738/how-to-setup-your-raspberry-pi-headless-8a905f

To get the WiFi dongle to work on my Pi, the post @ https://raspberrypi.stackexchange.com/questions/112062/raspbian-buster-lite-couldnt-communicate-with-wpa-supplicant (https://raspberrypi.stackexchange.com/questions/112062/raspbian-buster-lite-couldnt-communicate-with-wpa-supplicant) finally led me to a solution. The dongle I am using -"AirLink 101 Wireless N 150" is an older dongle, so it doesn't get automatically configured to run at boot up. The above linked to article itself points to another article that contained the answer. The answer being that you have to force the dhcpcd deamon to accept the dongle as a wiFi interface device:

It seems that dhcpcd does not aknowledge that it is a WiFi adapter, so we have to force it. Just add an interface section into /etc/dhcpcd.conf:

interface wlan0
env ifwireless=1
env wpa_supplicant_driver=nl80211,wext

The driver specification is required, otherwise wpa_supplicant will die with the error message

nl80211: Driver does not support authentication/association or connect commands nl80211: deinit ifname=wlan0 disabled_11b_rates=0
wlan0: Failed to initialize driver interface

After a reboot everything worked as expected, which is confirmed by the wpa_supplicant process running:

wpa_supplicant -B -c/etc/wpa_supplicant/wpa_supplicant.conf -iwlan0 -Dnl80211,wext

Notice that the configuration file used is /etc/wpa_supplicant/wpa_supplicant.conf, but if one named wpa_supplicant-wlan0.conf exists, it will be preferred.

So I edited the file /etc/dhcpcd.conf file (while SSH'd in via ethernet cable) to add those above 3 lines.

Edited with command: sudo nano /etc/dhcpcd.conf

After doing this I could then get into the WiFi settings panel from the raspi-config command. I did that and put in the SSID: cosmosnet and the passkey and saved those.

Then after a reboot the WiFi worked fine.

OK - so now I figure I am ready to try to install the nRF24 utilities referenced in the post @

3/22/2022 --

Downloaded, and wrote to the SD card, the base Raspberry Pi OS. This one:

Raspberry Pi OS with desktop
Release date: January 28th 2022
System: 32-bit
Kernel version: 5.10
Debian version: 11 (bullseye)
Size: 1,246MB

Downloaded from: https://www.raspberrypi.com/software/operating-systems/

I used the instructions in my Evernote note "Raspberry Pi OS Install" to burn the image to the SD card.

I found a web page with the p1's pinout reference, which I'll need in order to hook up the nRF24 chip to the pi. See "Raspberry gPIo" @ https://learn.sparkfun.com/tutorials/raspberry-gpio/gpio-pinout

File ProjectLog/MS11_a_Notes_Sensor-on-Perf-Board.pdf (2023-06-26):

## 11. Sensor on Perf Board

Purpose: Build an instance of the sensor circuit onto a perf-board.

Goal: Make a small-ish version of the ATTiny84 sensor processor and transmitter circuit that I can use in a real-world planter to better guage the performance of various capacitor-sensor designs.

Key References --

Sensor Design Article: This is interesting for sure. Notice how this sensor is made from two rings of copper, wrapped around PVC tubing. And they are then inserting the sensor down into another (wider) PVC tube and it is sensing (forming) capacitance through the insulating PVC tubing. I do note here, however, that they are sensing capacitance via the high-frequency pulsing/waveform method. So now I wonder if that approach does yield greater sensitivity and dynamic range. I may have to test this out.

A Portable Pull-Out Soil Profile Moisture Sensor Based on High-Frequency Capacitance @ https://www.mdpi.com/1424-8220/23/8/3806

Esp this photo: @ https://www.mdpi.com/sensors/sensors-23-03806/article_deploy/html/images/sensors-23-03806-g006.png (https://www.mdpi.com/sensors/sensors-23-03806/article_deploy/html/images/sensors-23-03806-g006.png)

To Modify RPi side .cpp code --

Use Kate on my desktop.

Then copy to the RPi using below command:

scp /home/jroc/Dropbox/projects/MoistureSensor/CapSensor /RPi/RPi_CapDataReceive.cpp pi@192.168.1.118:/home/rf24libs /RF24/examples_linux/

Then on the RPi, cd into the build directory and execute 'make'

BUT if this is the first iteration of the program, you need to first add it to CMakeLists.txt in the examples_linux directory (above the build directory).

NOTE: All the code is under git version control. So the executables for both the ATTiny and RPi are on my desktop.

Raspberry Pi Login --

Pi user is: pi. So SSH login is:

ssh pi@192.168.1.118
password: pi9012

And then once in, get into the working directory for the nRF24 utilities and programs:

cd /home/rf24libs/RF24/examples_linux/build

The run the RPi receiving program:

./RPi_CapDataReceive

Next Step: Three next steps. One, Fabricate a few different capacitor sensors to test. Two, modify code to measure and TX moisture (capacitance) data once/hour instead of continuously. Three, setup sensor in a real flower/plant pot in my house and run field tests on the sensors.

6/26/2023 --

Results: Success. Created power supply for the mobile sensor-circuit of 6/20/2023.

Build: Used a 5.5V wall-wart I had laying around. It's output actually read 6.0V. Created a voltage regulator circuit using an LD1117S33TR voltage regulator that I also had on hand.

Note: Per the Observation discussed below I increased the input cap value on the regulator from the recommended 0.1uf to 1.0uf to improve noise filtering. This did improve the ACK-back success rate from the RPi back to the ATTiny84's nRF24 module.

See photo at: /ProjectLog/MS11_b_Photo_SensorCircuit_PowerSupply.jpg

Observation: The nRF24 is sensitive to power supply noise. Up to now I've been powering it from a bench power supply. And the perf-board circuit reported back very, very, few acknowledgement errors; meaning the soldered in perf-board circuit was more stable and reliable than the breadboad circuit - which is not surprising. I initially used an 'active' LM2596 variable DC regulator to power the perf-board. When I did that I got a 100% acknowledgement error rate. Tho interestingly the RPi was receiving data from the ATTiny84 fine, it was only the ACKs from the RPi back to the ATTiny84's nRF24 that weren't making it through. When I put some extra capacitance on the DC output of the LM2596 board I got about a 25% success rate. When I put my old Radio Shack multimeter in-circuit to measure the current consumption of the sensor circuit I got a nearly 100% success rate - which I have put down to (inadvertent) noise suppression/smoothing caused by the meter. So then I powered the ATTiny84 sensor circuit using the same wall-wart, but with the passive 3.3V LD1117S33TR regulator. Using the recommended 10uF cap on the output, and the recommended .1uF cap across the input I got about a 50% acknowledgement error rate (multimeter not in-circuit). Using the recommended 10uF cap on the output, and increasing the input cap to 1.0uF I am now getting about a 30% acknowledgement error rate. So clearly power supply noise is an important consideration.

* Ultimately I plan to power the ATTin784 sensor circuit with a battery, so hopefully this will be a moot point. But it is interesting to see noisy power affects the radio reliability.

* I don't have an oscilloscope so I can't actually visualize the noise to understand it better.

* And I don't know what the noise is actually doing to cause the errors.

* I do have the wall-wart about 3 feet from the sensor circuit board, and the power regulator is about 6 inches from the sensor-circuit.

6/20/2023 --

Results: Success. Built the ATTiny84 sensor circuit onto a small perf-board. Have tested it an it is working.

NOTE: In fabricating the perf-board circut I did (of course!) make an incorrect connection - I mixed up the pin connections for the red error LED and the capacitor lead. Fortunately both those pins only need to be regular digital pins so I was able to simply swap those pins in the Arduino code to correct the error. From this point forward this correction is the 'official' pin mapping for sensor-capacitor connections to the ATTiny84.

The error was that I connected the cap lead to physical pin#3, and the red LED to physical pin#5; which was the opposite of how I had the breadboard circuit wired. So I reqired the breadboad circut to match, made the change in tiny84_pfCapMeasureAndTx.ino, uploaded the revised sketch to the ATTiny84 chip, tested it, and all was well.

Photos of Perf-Board: See /Physical-Construction/Sensor/SensorCircuit_On-perfBoard_Photo.jpg.

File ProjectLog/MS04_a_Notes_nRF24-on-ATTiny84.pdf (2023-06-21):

# 4. nRF24 on ATTiny84 - Conversation

Purpose: Having successfully demonstrated ability to have nRF24 that is connected to the ATTiny84 continuously send out data, and for the chip on the Raspberry Pi to see it (See note titled "nRF24 on ATTiny84 - Blind Data Send."); now I want to get a back-and-forth 'conversation' going between the two. So the goal here is to have the ATTiny84 send out data packets; the RPi to receive them and reply back with an acknowledgement packet that the ATTiny84 sees in return, and then have the ATTiny84 make some update to it's next data packet and send that updated packet out to the RPi. What I want to see on the RPi side is the revised data packets coming in from the ATTiny84 to "prove" the two chips are in a conversation. (See note titled "nRF24 on Raspberry Pi.")

Goal: From the monitor on the Raspberry Pi, see that a back-and-forth conversation between the ATTiny84 and RPi is occurring.

Key References --

What I finally discovered on 3/25 is the below site is the key resource for the nRF24:

nRF24 / RF24 github repo @ https://github.com/nRF24/RF24

See the pin connection table at the bottom of the following page (which also appears to be the home of the documentation that goes with the above github repo):

https://rf24.readthedocs.io/en/latest/

Another key reference is the so-called Arduino Core for the ATTiny family. Above reference says the code there is based on the 'SpenceKonde' core. The home for this is @ https://github.com/SpenceKonde/ATTinyCore. See the readme file there for documentation, including how to reference pins inside the code that match up to the processor physical pins. It says to use the Port and Number as reference. E.g., ATTiny84 physical pin 12 would be referenced as 'PA-1' in the code. As in: const int ledPin = PIN_PA1; // the pin that the led is wired to

"Addressing" with the RF24's is confusing to me. So called 'pipes' are opened for reading and writing; and there are notes in the Arduino RF24.h file about addresses associated with these pipes. So far I have not been able to work out what's really going on. In RF24.h there was a reference to the below web page re addressing:

Improve RF24 Radio Performance With Proper Addressing Schemes @ http://maniacalbits.blogspot.com/2013/04/rf24-addressing-nrf24l01-radios-require.html (http://maniacalbits.blogspot.com/2013/04/rf24-addressing-nrf24l01-radios-require.html)

05/29/2022 --

Initial Success!

ATTiny Software: AckPayloads_jrrMod. In Arduino IDE I modified the acknowledgementPayloads.cpp code for the ATTiny to simplify it by removing all the serial-monitor 'print' statements, and by removing the Receive mode option. The Arduino sketch is named: AckPayloads_jrrMod. So for the ATTiny84 side the code creates a device that is transmit only.

Use acknowledgementPayloads on Raspberry Pi Side. NOTE: This is the code that uses the 'autoack with payload.' Don't confuse this with the manualAcknowledgements.cpp code. So on the RPi side this pairs with acknowledgementPayloads.

AckPayloads_jrrMod_2. In reconstructing this Milestone after the failure from Milestone #5 I created a tweaked tiny84 side sketch from the original AckPayloads_jrrMod - I named it AckPayloads_jrrMod_2. Did this to use the LEDs better and my now standard errorLED routine.

I also added a RED led to be able to signal errors detected in the code.

When I run the ATTiny84 device with the acknowledgementPayloads app on the RPi side - with no code mods by me on this first run - I get a continuous stream of:

Received 8 bytes on pipe 1: Hello 1 Sent: World 0
Received 8 bytes on pipe 1: Hello 3 Sent: World 2 Received 8 bytes on pipe 1: Hello 5 Sent: World 4 Received 8 bytes on pipe 1: Hello 7 Sent: World 6 Received 8 bytes on pipe 1: yyyyy 7 Sent: World 8 Received 8 bytes on pipe 1: Hello 9 Sent: World 8 Received 8 bytes on pipe 1: Hello 9 Sent: World 10 Received 8 bytes on pipe 1: Hello 11 Sent: World 10 Received 8 bytes on pipe 1: Hello 11 Sent: World 12 Received 8 bytes on pipe 1: Hello 13 Sent: World 12 Received 8 bytes on pipe 1: Hello 13 Sent: World 14 Received 8 bytes on pipe 1: Hello 15 Sent: World 14 Received 8 bytes on pipe 1: Hello 15 Sent: World 16 Received 8 bytes on pipe 1: Hello 17 Sent: World 16 Received 8 bytes on pipe 1: yyyyy 17 Sent: World 18 Received 8 bytes on pipe 1: xxxxx 17 Sent: World 18 .....

The "yyyyy" and "xxxxx" lines are showing that occasionally the RPi doesn't respond back properly, or in a timely manner; and/or the ATTiny84 side isn't picking up the carrier of the RPi response. Those occasional glitches are rare on my bench. The two chips screamed through to increment 255 in a a second or so with only about 5 mis-hits.

SO - OK, now I can exchange data between the two devices. Next - I think it's time to connect an analog input on the ATTiny84 side and see that varying data on the RPi side.

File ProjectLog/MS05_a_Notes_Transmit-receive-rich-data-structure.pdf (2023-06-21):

# 5. Transmit/Receive Rich Data Structure (e.g., capacitance)

Purpose: Have the ATTiny84 send a richer data structure to the RPi, a structure suitable for the capacitance moisture measurement, and have the RPi show these values on the terminal.

Goal: From the monitor on the Raspberry Pi, see the capacitor value. Ideally, see varying values on the RPi, in realtime, as I vary a pot.

Key References --

For NOT using a 555 timer to do this - much simpler:

https://www.arduino.cc/en/Tutorial/Foundations/CapacitanceMeter

For WHY not to use a 555 timer:

Is the NE555 the IC I need, and if not, what do I replace it with? @ https://electronics.stackexchange.com/questions/486156/is-the-ne555-the-ic-i-need-and-if-not-what-do-i-replace-it-with/486157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 (https://electronics.stackexchange.com/questions/486156/is-the-ne555-the-ic-i-need-and-if-not-what-do-i-replace-it-with/486157)

"Modern microcontrollers work at lower voltages, and typical everything enabled, even if not used (example datasheet) at say 12 MHz clock rate (which should be way more than enough to synthesize any signal shape that the NE555 might create) half of that; but realistically, you'd run your MCU at a lower frequency, and let it sleep most of the time when using it to replace an NE555 in most applications."

Raspberry Pi Login --

Pi user is: pi. So SSH login is:

ssh pi@192.168.1.118
password: pi9012

And then once in, get into the working directory for the nRF24 utilities and programs:

cd /home/rf24libs/RF24/examples_linux/build

Modify RPi side .cpp code --

Use Kate on my desktop.

Then copy to the RPi using below command:

scp /home/jroc/Dropbox/projects/MoistureSensor/nRF24-with-Rpi/CapDataReceive_02.cpp pi@192.168.1.118:/home/rf24libs/RF24/examples_linux/

Then on the RPi, cd into the build directory and execute 'make'

06/27/2022 --

Finally! Figured it out. The 'garbage' data bring seen on the RPi side is not due to any difference in endian-ess. It is due to differing ways that the two platforms (ATTiny/Arduino and RPi) pack/unpack bytes into data structures. After a lot of hours - many of those working out how to get C++ to show me the raw bytes of variables, how to get cout to display them, and how to effect a "manual" loading of variables from raw bytes - I was able to send the dummy data structure from the ATTiny84, have the RPi receive it as a raw unit8_t [] array, and use a function I created to load the received bytes into a C struct that matches the one created on the ATTiny84 side.

The code that works for this is:

ATTiny Arduino Code: /CapMeasureAndTransmit_02

RPi Code: CapDataReceive_02c.cpp

Also for reference, see my posting about this issue on the rf24libs github "Add Info Regarding Byte Alignment or Packing Mismatches" @ https://github.com/nRF24/RF24/issues/847

06/18/2022 --

RPi Software. Starting from acknowledgementPayloads.cpp I coded up the Pi side, the receiver side. This is CapDataReceive_02.

ATTiny84 Software. Starting from AckPayloads_jrrMod I coded up the tiny84 side. This is CapMeasureAndTransmit_02. At this milestone this does NOT actually measure any capacitor. All I'm doing here is hard-coding some dummy data just to get the code data structures and architecture right.

Result for the Day:

Success!. A constant, rapid, stream of RPi scrolling on the SSH terminal window "...success..." and showing the dummy data I am sending out from the tiny84.

EXCEPT tho - the chargeTime isn't being reported out by the RPi correctly. I set this value to 0 in the tiny84; but the RPi keeps showing it as charge time: 754974720.

Investigation. Spent a fair bit of time trying to work this out; including adding a new float variable both before and after the chargeTime variable in the tiny84 transmit payload structure. When I did that the first float and the chargeTime both showed up correctly on the RPi side with my set values of "0." But now testFloat2 was out of wack. Then when I revised the tiny84 side to increment testFloat1 by 0.1 on each successful transmit cycle it also began to display with wacky values on the RPi side - tho chargeTime continued to properly display as "0."

Speculation: I can't really transmit data values across the airwaves with nRF24? Meaning that you have to convert them to text (e.g., HEX char strings) and send as text, then convert back on the other side. In a quick google search I did find this statement, which must be true, and would support my speculation: "The nRF24 just sends and receives bytes. It is up to the programs to interpret the bytes correctly."

Long thread about endian conversion. @ https://stackoverflow.com/questions/105252/howdo-i-convert-between-big-endian-and-little-endian-values-in-c. (https://stackoverflow.com/questions/105252/how-do-i-convert-between-big-endian-and-little-endian-values-in-c) This may be a good quick& dirty

to try:

/ can be used for short, unsigned short, word, unsigned word (2-byte types)
#define BYTESWAP16(n) (((n&0xFF00)>>8)|((n&0x00FF)<<8))

// can be used for int or unsigned int or float (4-byte types) #define BYTESWAP32(n) ((BYTESWAP16((n&0xFFFF0000)>>16))| ((BYTESWAP16(n&0x0000FFFF))<<16))

// can be used for unsigned long long or double (8-byte types) #define BYTESWAP64(n) ((BYTESWAP32((n&0xFFFFFFFF00000000)>>32))| ((BYTESWAP32(n&0x00000000FFFFFFFF))<<32))

06/17/2022 --

Milestone #3 Working Again. OK, I now have Milestone #3 working again. I might be that on 6/15 I was using the wrong sketch on the tiny84 side. I think I was running the original 'GettingStarted_jrrMod' sketch when the proper sketch to run for Milestone #3 is 'rf24ATtiny84_2rdTry_TxOnly.' Starting with
rf24ATtiny84_2rdTry_TxOnly I created a slight variation to leverage the two LEDs, and my 'errorLED' subroutine. This new sketch is 'BlindTransmit.'
BlindTransmit does report an error - RED LED on steady. This means that on the tiny84 after a transmit attempt the call to bool report = radio.write(&payload, sizeof(payload)); returns false. But in BlindTransmit I ignore that and just keep transmitting. In the scanner on the RPi I am now seeing decent hit-rates for carrier signal on channel 4C.
New Info. So I think this has also now given me a little piece of additional info - 'Report' will return false if either the nRF24 itself believes it wasn't able to send the data out for some reason OR it did send it out, but it didn't get an ACK packet back that it expected to.
Milestone #4 Working Again. But with a lot of transmission failures and time-outs. Which, maybe was true at the original run of Milestone #4 but I just wasn't paying as much attention to that fact at that point. Maybe the errors have to do with the fact that in the current code base the tiny84 side is running in low power mode. Or maybe it has to do with timing and/or delays I have in my code. But at least we're back to having some sort of back and forth conversation now.
I used AckPayloads_jrrMod_2. For this re-do of Milestone #4 I modified the tiny84 side code to use the two LEDs and my now standard errorLED routine. So this test used AckPayloads_jrrMod_2 on the tiny84 side.
AckPayloads_jrrMod. The original I used back in Milestone #4. This does give far, far, fewer errors. So there must be some timing difference between the two programs. Tho even this one has periods of errors. Maybe due to some periodic confluence of timing delays on both side side of the code (tiny84 and RPi)? Maybe some rf interference caused by some other device? Something to watch for.
Radio 0 for RPi. Note that when running the RPi side code, the acknowledgementPayloads
code, you must choose 'Radio 0' when it prompts for that.

Re-Coding the RPi Side. Starting from acknowledgementPayloads.cpp I coded up the Pi side, the receiver side. This is CapDataReceive_02.
I haven't coded up the tiny84 side yet. But just for grins I ran my newly coded CapDataReceive_02 program on the RPi and just fired up the tiny84 running the AckPayloads_jrrMod sketch. There was a backand-forth, with the RPi showing garbage for the capacitance data, as of course it should since what it was actually receiving was the "Hello" and an integer number. But there was a steady back-and-forth between the two radios, so that is encouraging.

Result for the Day:

Hypothesis As to the 6/15 Failure. I think a few mental lapses caused the failures. First, on the RPi side I started from the
manualAcknowledgements.cpp source code, while on the tiny84 I started from AckPayloads_jrrMod. These two don't match up. I should have started from the acknowledgementPayloads.cpp code. Then on rolling back I was also mixing up the paring of the code to run on the tiny84 / RPi. And to boot I had made some tweaks for the LED blinking so I could get better signalling on the tiny84 side of which error condition I was in.
Begin Again. So now it's time to "...begin again..." This time I will start with the code on the RPi side, starting from acknowledgementPayloads.cpp. On the tiny84 side I'll start with AckPayloads_jrrMod.ino.
Coded the Raspberry Pi Capacitance Receive Code.

06/15/2022 --

Software.

Upload the CapMeasureAndTransmit sketch to the ATTiny and see if it works.

Result for the Day:

Failure. Now nothing is working. There was a brief moment, after rolling back to milestone #4, that the two were talking to each other - tho there were a lot of error transmissions (i.e., the RPi seeing those "xxxx" packets from the tiny84); but then the RPi reported 'silence for over 6 seconds. After that point I've not been able to get anything working. I've rolled all the way back to milestone #3 - just running the scanner on RPi to see if I can even just see a signal from the ATTiny84, using the original
'GettingStarted_jrrMod' sketch on the tiny84. Nothing. I've swapped out the nRF24 chips on both the tiny84 and RPi - nothing. I've used a new ATTiny84 chip - nothing. No clue what's going on.

In fact even the scanner running in the RPi froze and I had to reboot the Pi.

As of 2:19pm: I put a new nRF24 cip on the RPi and am running the scanner, while the 'GettingStarted_jrrMod sketch on the tiny84 - the scanner is now spitting out lines in the ssh terminal, and it ocassionally shows a signal hit of '1' for the transmitting tiny84. But mostly I'm getting '-'; no signal detected from the tiny84. The scanner is showing the usual hits from what I believe is the 2.4Ghz wifi band. Which would seem to say to me that the problem is on the ATTiny84 transmit side.

06/14/2022 --

Hardware Setup.

Using the reference design/approach from https://www.arduino.cc/en/Tutorial/Foundations/CapacitanceMeter (https://www.arduino.cc/en/Tutorial/Foundations/CapacitanceMeterI) I created a capacitor tester on a breadboad and hooked into into the ATTiny. I added a potentiometer so I could vary the calculated capacitance in order to be able to simulate that in my two transmit / receive programs.

Software.

For the ATTiny84 transmit side I started with the 'Conversation' code from my milestone #4, and modified it using the example code from the above key reference.

But - I didn't add the code to actually measure capacitance. To start with I am just hard-coding in values just to get the two nodes talking to each other and the RPi showing me the dummy received capacitance data structure it gets from the tiny84. I just want to get this part working to start with.

For the RPi side I started with the 'manualAcknowledgements.cpp code and modified it to receive and display the capacitance data structure the tiny84 is now sending out.

Result for the Day:

Created and successfully compiled the RPi side code: CapMeasureAndTransmit_Rx.cpp

Created the tiny84 side code, and successfully compiled it in the Arduino IDE, but did not upload to the ATTiny yet.

06/00/2022 --

Software.

Upload the CapMeasureAndTransmit sketch to the ATTiny and see if it works.

Result for the Day:

xxxx

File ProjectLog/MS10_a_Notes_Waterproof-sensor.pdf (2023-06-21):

# 10. Waterproof Sensor

Purpose: Fabricate an Effective Waterproof Capacitance Sensor.

Goal: Make a sensor that has adequate sensitivity and range, and is waterproof..

Key References --

Sensor Design Article: This is interesting for sure. Notice how this sensor is made from two rings of copper, wrapped around PVC tubing. And they are then inserting the sensor down into another (wider) PVC tube and it is sensing (forming) capacitance through the insulating PVC tubing. I do note here, however, that they are sensing capacitance via the high-frequency pulsing/waveform method. So now I wonder if that approach does yield greater sensitivity and dynamic range. I may have to test this out.

A Portable Pull-Out Soil Profile Moisture Sensor Based on High-Frequency Capacitance @ https://www.mdpi.com/1424-8220/23/8/3806

Esp this photo: @ https://www.mdpi.com/sensors/sensors-23-03806/article_deploy/html/images/sensors-23-03806-g006.png (https://www.mdpi.com/sensors/sensors-23-03806/article_deploy/html/images/sensors-23-03806-g006.png)

To Modify RPi side .cpp code --

Use Kate on my desktop.

Then copy to the RPi using below command:

scp /home/jroc/Dropbox/projects/MoistureSensor/CapSensor /RPi/RPi_CapDataReceive.cpp pi@192.168.1.118:/home/rf24libs /RF24/examples_linux/

Then on the RPi, cd into the build directory and execute 'make'

BUT if this is the first iteration of the program, you need to first add it to CMakeLists.txt in the examples_linux directory (above the build directory).

NOTE: All the code is under git version control. So the executables for both the ATTiny and RPi are on my desktop.

Raspberry Pi Login --

Pi user is: pi. So SSH login is:

ssh pi@192.168.1.118
password: pi9012

And then once in, get into the working directory for the nRF24 utilities and programs:

cd /home/rf24libs/RF24/examples_linux/build

The run the RPi receiving program:

./RPi_CapDataReceive

Next Step: Assemble the sensor circut onto a perf-board, then use it in a real plant pot, indoors, while using a normal, store-bought, plant water moisture meter to gauge if this sensor would be able to discern Dry - Moist - Soaked.

6/16/2023 --

Results: Partial Success. I am getting stronger readings with the more robust sensor, and good solid readings through the membrane of a waterproofing baggy. But the dynamic range across dry - moist -soaked may not be sufficient.

Design: Fabricated a beefy sensor from sheet aluminium. Using the Dremel I cut a strip in two with an interlocking zig-zag pattern. Then I put the whole sensor into a baggy. See photo.

Open Air: 0 pF

Placing thumb On Sensor: 4 pF.

In Dryish Soil: 25-27 pF

Watered Soil: 29-33 pF

Fully Drenched Soil: 30-33 pF

Discussion:

06/10/2023b --

Results: Failure. Wrapped sensor stick in Glad Cling-Wrap (LDPE). I did wrap about 10 layers (to make it waterproof). Measurements:

Open Air: 9-10 pF in open air

Placing Thumb On Sensor: No real change

In Dry Soil: NA, didn't have any dry soil to test.

"Watered" Soil: NA, didn't have any to test.

Fully Drenched Soil: 9-10pF.

Discussion: So, the Cling-Wrap is not at all effective.

06/10/2023a --

Results: Partial Success. Took my existing popsicle stick sensor and stuck it into a baggy. Measurements:

Open Air: 9-8 pF in open air

Placing Thumb On Sensor: 11-12 pF range

In Dry Soil: 12-12.5 pF.

"Watered" Soil: 15-16pF.

Fully Drenched Soil: 15-16pF.

Discussion: So, ok, inside plastic kinda works; but the range of sensitivity isn't very good. I will note, tho, that the pot I used only allowed half of the popsicle stick to be submerged. would the sensitivity be better if it was fully underground?

Prep --

Just stuck the sensor stick into a baggy. Then worked the bagged stick into a pot with soil in it. Note, tho, that the pot I used only allowed half of the popsicle stick to be submerged. See photo.

Software --

RPi: No change.

ATTiny: No change from MS09 sketch.

Git Commit: No commit made as yet.

Hardware --

No change other than placing the sensor stick into a plastic bag.

Next Step: Unsure.

Gorilla Waterproof Patch and Seal Clear Spray Paint: This is probably the best answer. Available at Lowes/Home-Depot. $15 for a spray bottle. Not cheap. And I wonder if it would be good for my bird-bath bowel??

Polyurethane: As a finishing product - the spray I used, likely any can of liquid poly I might be able to buy at Lowes and such - these are not waterproof. But "...thermoset polyurethanes can practically have zero water absorption compared to other known materials."

Low-Density Polyethylene: Cling-Wrap. See 06/10/2023b test. A fail.

"It has a melting point of 239 degrees Fahrenheit (115 degrees Celsius), is waterproof, provides electrical insulation, and is resistant to both acids and bases." [https://www.edlpackaging.com/blog/understanding-the-differences-between-polyolefin-packaging-films/] (https://www.edlpackaging.com/blog/understanding-the-differences-between-polyolefin-packaging-films/])

And as I was researching all this I see many posts saying that "In response to consumer concerns over chemicals in plastics, SC Johnson changed the forumla for Saran Wrap, substituting LDPE (low-density polyethylene) for the PVDC, which eliminated DEHA in the product. || Other major brands of cling wrap, including Glad Wrap, have also changed to LDPE, but a few, like Reynolds Foodservice Film (sold at Wal-Mart and on Amazon) continue to use PVDC."

High-Density Polyethylene: High-density polyethylene (HDPE) has a crystalline structure with tightly packed molecules. This material’s polymer structure makes it durable and a popular choice for rigid packaging containers. It also has greater resistance to chemicals and extreme temperature conditions, with a melting point of 275 degrees Fahrenheit (135 degrees Celsius). Like LDPE, HDPE is waterproof, low cost, and lightweight. [https://www.edlpackaging.com/blog/understanding-the-differences-between-polyolefin-packaging-films/]

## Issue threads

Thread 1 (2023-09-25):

Tx Retry Infinite Loop After 4 Read/Tx cycles

JeffRocchio, 2023-09-25:
After a variety of updates to both the ATTiny and RPi code I noticed in a validation run that after 4 successful Cap read and transmit cycles the ATTiny-RPi pair is stuck in a Tx/Ack-Rx retry loop. The ATTiny side is looping through the logic that is the 'Error ID #2' logic - it transmits but doesn't see an Ack packet back from the RPi. So it keeps retrying. Heartbeat and errorFlash are working - I do see the 'Error-2' reports on the red led. On the RPi side it is receiving the Tx's from the ATTiny's radio chip. I see the ctErrors value keep counting up on the RPi SSH terminal session.

JeffRocchio, 2023-09-26:
OK, so I now have a working version of the program with the bug removed. The trigger for the bug was the redefinition of the ackPayload struct in order to support the command/response protocol. When I made that change to both the ATTiny and RPi code I got the error. So I then re-redefined the struct, as noted below, and now it works. So my theory is that the 'data boundaries' in the struct have to be at 4-byte intervals in order for either the nRF24 chipset/board and/or the ATTiny to pack and unpack the structs properly.

This definition causes the issue to occur:
```
struct AckPayloadStruct {
    uint8_t command;      // Command ID back to sensor | 1-byte
    uint8_t uiCmdData;    // Command data field: unsigned int | 1-byte
    int iCmdData;         // Command data field: signed int | 2-bytes
    uint32_t uliCmdData;  // Command data field: unsigned long int | 4-bytes
    float fCmdData;       // Command data field: float | 4-bytes
};
AckPayloadStruct ackPayload;

```

This definition works fine:
```
struct AckPayloadStruct {
    uint32_t command;
    uint32_t uliCmdData;
};
AckPayloadStruct ackPayload;

```
Some additional testing may reveal what constraints are really at work on defining structs that work.

JeffRocchio, 2023-09-28:
This is resolved in commit dd80da1. Although I do not, at this time, fully understand the 'rules' for defining data structs that will work, are bullet-proof, for data comms between the ATTiny and RPi using the nRF24 chip. That will have to be an exploration for another day - BUT see the posting about this at the below link, wherein it is stated:

> What you're fighting is called memory misalignment. It can be solved by making sure data fits into 32-bit wide boundaries. For example, your test data sends an 11-byte string in the first segment of the payload, but it would be better if this was the last segment. If you look at the raw hex data, you may have noticed that everything after the first c-string is offset by 1 byte.

[Add Info Regarding Byte Alignment or Packing Mismatches](https://github.com/nRF24/RF24/issues/847)

Closed 2023-09-28.

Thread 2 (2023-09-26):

Error ID #3 Infinite Loop

JeffRocchio, 2023-09-26:
In working through issue #1 I discovered that when errorID #3 occurred (this can happen in RadioComms::Update() function in the case 2 section of code) then my non-blocking logic has us in an infinite loop back up in the Dispatcher::dispatch() function.

What happens is that when error-3 occurs I am in phase-3 in the Dispatcher; which is this segment of code:
```

case 3: // Wait for and fetch ACK payload.
   if(radio.ackAvailable()) {
     _ackPayloadPtr = radio.getAckPayload();
     _phase = 4;
   }
  break;

```
So the dispatcher logic flashes out the errorID, clears the errorID, but is then "stuck" in dispatcher phase-3; with, apparently, radio.ackAvailable() never returning true. So every call from that point forward just goes to case 3, fails the test, breaks....repeat.

Now, as to why we got to error condition #3 instead of error#2 when we have auto-ack on for the nRF25 chip...I don't know. My best theory is that when I control-C'd out of the RPi_CapDataReceive program the nRF24 chip-board was left with the radio in "listening' mode so it did a receive/ack with the ATTiny; but the ack payload was NULL as it got emptied out on the last Tx exchange just before I exited the RPi program (which I did in order to recompile it). So the ATTiny logic keeps seeing the 'report' as coming back true; but there is no payload; so that combo gets trapped into errorID 3 in RadioComms::Update(), phase 2 (case 2:).

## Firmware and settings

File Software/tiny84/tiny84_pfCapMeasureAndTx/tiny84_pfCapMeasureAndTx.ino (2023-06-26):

/*   ATTiny84 Moisture Sensor Project
 *   -----------------------------------------------------------------------------------------------------
 *   
 *  Arduino IDE 'sketch' for the ATTiny84 MCU prototype capitance moisture sensor.
 *   
 *  This project is under local git version control, in folder:
 *  /home/jroc/Dropbox/projects/MoistureSensor/CapSensor
 *  Refer to git for version history and associated comments.
 *
 *      06/20/2023: Had to change some pin mappings. I built a version of the sensor circuit onto a
 *  perfBoard. But in doing so I mixed up one of the pins for the cap sensor with the pin for the
 *  Red LED. So I needed to change those pin definitions in here in the code.
 *
 *      06/05/2023: Success!! No change to code from 6/3 below; just this note that this code 
 *  worked. It is licking away, showing, after about 15 minutes, 1768 successful transmissions of 
 *  the cap value for my home-made cap sensor ranging between 8-9 pF. It also successfully 
 *  reported the value of the 10pF cap (showing it as 8xpF, close to what my multimeter also 
 *  measured). NOTE that I have not done anything to calibrate the stray capacitiance constant, 
 *  which I left at the value of 24.48 that was in the original author's code.
 *
 *      06/03/2023: Initial 'sketch' to implement approach for measuring pico-farad level
 *  capacitance. This approach uses the methodology described by the article "Capacitance measurement 
 *  with the Arduino Uno" by Jonathan Nethercott
 *  @ https://wordpress.codewrite.co.uk/pic/2014/01/21/cap-meter-with-arduino-uno/
 *      NOTE tho that the above post is from 2014 and Jonathan does not appear to be active
 *  any longer. However, this approach of his is referenced, and used, all over the internet and on
 *  YouTube.
 *      To be safe, I made a pdf of the blog post on this approach and saved it into the docs and
 *  references folder as Pico-farad-cap-measurement-with-Arduino.pdf.
 *   
 *  A detailed log of this project is being recorded in my Evernote account, in the notebook
 *  "Moisture Sensors."
 */

// ==== Pull in Required Libraries
#include <SPI.h>
#include "RF24.h"

// ==== ATTiny84 Pin Reference Definitions
/*************************************************************************************************
 *    Define references to the logical pins we'll be using.
 *    NOTE: I am using the PIN references per SpenceKonde attiny core recommendation. The
 * pin references in the original demo code did not work for the tiny84. After working out the
 * whole Arduino core thing, and how the logical-physical pin mappings are actually defined by
 * the core's author, I went to the SpenceKonde github and inspected his documentation, in
 * which he states that for digital pins, use the 'logical' port numbering schema - 
 *  e.g., "PIN_PA#" or PIN_PB#." For the analog pins use the analog channel number as shown on
 *  the pinout diagram. E.g., us 'A7' for ADC7, physical pin #6; 'A0' for ADC0, physical pin 13.
 *    BUT note that I am currently using core 1.5.2; for version 2.0.0 of the core the pin
 *  reference scheme is being updated to a more commonly used schema. So watch for this.
 */

  /* Logical pin names representing connection of ATTiny84 to nRF24 chip */
#define CE_PIN PIN_PA2
#define CSN_PIN PIN_PA3

  /* LEDs to signal status. */
const int greenLedPin = PIN_PA1;  // Physical pin #12 The pin that a green led is wired to
const int errorLedPin = PIN_PB2;  // Physical pin #5. The pin that a red led is wired to

  /* For capacitance measurement */
const float IN_STRAY_CAP_TO_GND = 24.48;  // Stray capacitance, used as 'C1' in schematic. 
const float IN_EXTRA_CAP_TO_GND = 0.0;    // Extra capacitance can be added to measure higher values.
const float IN_CAP_TO_GND  = IN_STRAY_CAP_TO_GND + IN_EXTRA_CAP_TO_GND;
const int MAX_ADC_VALUE = 1023;

#define voltReadPin    A0                 // Physical pin#13 - analog 'channel 0' for measuring voltage
#define chargePin      PIN_PB1            // Physical pin#3 - pin to charge the capacitor - connected to one end of the charging resistor
//#define dischargePin   PIN_PB0          // NOT USED FOR pF level measurements. [Physical pin#2 - pin to discharge the capacitor]
#define resistorValue  3000000.0F         // 3 Meg Ohm. For accurate calculation must match actual charging resistor value

// ==== Global Variables
/*************************************************************************************************
 *    Being sloppy here as I experiment and learn, relative to relying heavily on
 * globals. Although, my mindset clearly comes from desktop/server coding. Perhaps efficient
 * coding on an MCU is paradigmatically different vis-a-vis globals? */

  /* Some needed variables for cap measurement. */
unsigned long startTime;
unsigned long elapsedTime;
float microFarads;                // floating point to preserve precision during calculations
float nanoFarads;

  /* nRF24: Declare, and instantiate, an object for the nRF24L01 transceiver. */
RF24 radio(CE_PIN, CSN_PIN);

  /* nRF24:    
   *    Declare an array to hold node addresses. In this case we have only two nodes -
   * the RPi and this node, the tiny84.
   *    NOTE from original source: "It is very helpful to think of an address as a path 
   * instead of as an identifying device destination."
   *    Jeff Comment: I don't really understand how these "addresses" are used, this 
   * needs further rabbit-holing my me at some point. */
uint8_t address[][6] = {"1Node", "2Node"};

  /* nRF24:    
   *    Comment in original source: "To use different addresses on a pair of radios
   * we need a variable to uniquely identify which address this radio will use to 
   * transmit."
   *    This variable is used later to de-reference an entry in the address[][] array
   * declared above. */
bool radioNumber = 1;             // 0 uses address[0] to transmit, 1 uses address[1] to transmit

  /* nRF24: Used to control whether this node is sending or receiving. */
bool role = true;                 // true = TX role, false = RX role

  /* nRF24:     
   *    Define, and declare, a struct to hold the transmit payload.
   *    NOTE: This struct must match the 'receive' payload structure declared on
   * the RPi side. */
struct TxPayloadStruct {
  float capacitance;
  uint32_t chargeTime;            // Time it took for capacitor to charge.
  char units[4];                  // nFD, mFD, FD
  uint32_t ctSuccess;             // count of success Tx attempts tiny84 has seen since boot
  uint32_t ctErrors;              // count of Tx errors tiny84 saw since last successful transmit
  char statusText[12];            // For use in debugging. Be sure there is space for a NULL terminating char

};
TxPayloadStruct txPayload;

  /* nRF24:     
   *    Define, and declare, a struct to hold the acknowledgement payload.
   *    NOTE: This struct must match the 'ack' payload structure declared on
   * the RPi side. */
struct RxPayloadStruct {
  char message[11];               // Incoming message up to 10 chrs+Null.
  uint8_t counter;
};
RxPayloadStruct rxAckPayload;




// ==== Setup Procedure
/*************************************************************************************************
 *  Make everything ready so that we can begin to sense and transmit.
 */
void setup() {

    /* Init LED signal pins. */
  pinMode(greenLedPin, OUTPUT);
  pinMode(errorLedPin, OUTPUT);
  digitalWrite(errorLedPin, HIGH);    // Turn LEDs on the verify operation and see where we are at this point
  digitalWrite(greenLedPin, HIGH);
  delay(3000);                        // Pause for humans to verify LEDs at this point.

    /*    Init capacitance measurement pins. */
  pinMode(chargePin, OUTPUT);
  digitalWrite(chargePin, LOW);       // Start with 0 volts on charge pin.
  pinMode(voltReadPin, OUTPUT);
  digitalWrite(voltReadPin, LOW);     // Start with the analog pin low, 0 volts.

    /* Init the nRF24 radio on the SPI bus. If this fails, go into an infinite
     * loop, stuck in that error condition. If this does happen, signal that
     * with the LEDs. */
  if (!radio.begin()) {
    while (1) {
        errorLED (9);                 // Call this error #9.
      } // end while
  }

    /* Set the PA Level low to try preventing power supply related problems
     * because these examples are likely run with nodes in close proximity to
     * each other. */
  radio.setPALevel(RF24_PA_LOW);      // RF24_PA_MAX is default.

    /* To use ACK payloads, we need to enable dynamic payload lengths (for all nodes) */
  radio.enableDynamicPayloads();

    /*    We wish to receive Acknowledgement payloads back from the RPi. 
     *    To be able to do so We need to enable this feature for all nodes (TX & RX). 
     * (akk packets have no payloads by default.) */
  radio.enableAckPayload();

    /*    Original source code comment: "set the TX address of the RX node into the TX pipe. 
     * Always uses pipe 0 for transmit."
     *    Jeff Note: This is quite confusing. I haven't yet backtracked this to work
     * out what it's really saying. But I assume it's saying that we need to load an
     * address into the transmit pipe that the receiving node will recognize and accept
     * as a valid "one of us." */
  radio.openWritingPipe(address[radioNumber]);

    /*    Original Source Comment: "set the RX address of the TX node into a RX pipe."
     *    Jeff: An interesting way to specify the row '0' in the address array.
     * I guess this approach guarantees that transmit and receive addresses
     * will always be 'the opposite' of each other. */
  radio.openReadingPipe(1, address[!radioNumber]);  // using pipe 1 to receive.

    /* Load the txPayload structure with initial defaults. */
  txPayload.capacitance = 0;                        // calculated capacitance
  txPayload.chargeTime = 0;                         // Time it took for capacitor to charge.
  memcpy(txPayload.units, "---", 3);                // capacitance units
  txPayload.ctSuccess = 0;                          // running count of no-error transmissions
  txPayload.ctErrors = 0;                           // running count of transmissions errors
  memcpy(txPayload.statusText, "Initial ", 8);      // status message

    /* Put radio in transmit mode. */
  radio.stopListening();


} // END setup()



// ==== Transmission Loop
/*************************************************************************************************
 *    OK, we've setup the ATTiny84 and the radio chip. Now go into an infinite loop, continuously 
 * transmitting data, seeking a valid acknowlegement of receipt; then repeat....
 *    NOTE: I removed the else portion of code pertaining to receive nodes as here I am only 
 *  allowing the ATTiny to be a data/sensor transmitter; with the RPi to be the receiver. 
 */
void loop() {
  unsigned long start_timer = micros();                         // time the Tx cycle - obtain start time
  bool report = radio.write(&txPayload, sizeof(txPayload));     // attempt transmit - obtaining 'success' or 'timeout' result
  unsigned long end_timer = micros();                           // time the Tx cycle - obtain end time

  if (report) { // IF report is true than nRF24 chip sent the payload out & got an ack back
        /* report is TRUE: meaning the nRF24 chip sent the payload out & got an ack back. 
         * Since we have full success, clear any prior error conditions. */
      digitalWrite(errorLedPin, LOW);
      //memcpy(txPayload.statusText, "Success    ", 11);        // clear error status text
      txPayload.ctSuccess = txPayload.ctSuccess + 1;            // we have a Tx/ack success, increment the success tracking counter.

        /* See if we got a receipt ACK payload back from the receiver (this would be an auto-ack payload).
         * Declare variable to hold the pipe number that received the acknowledgement payload. */
      uint8_t pipe;
      if (radio.available(&pipe)) {                             // ACK if-then block. Test for ack payload, which will also return the pipe number that received it.
        radio.read(&rxAckPayload, sizeof(rxAckPayload));        // get incoming ACK payload. Tho doing nothing with it on this side of the conversation.
        delay(20);                                              // brief pause, then fall through to bottom of loop and keep transmitting.
      } else {
        /* Radio chip sent the tranmission out, but did not receive an ACK data payload back.
         * Show this with the LED. But then fall through to bottom of loop and keep transmitting. */
        errorLED (2);                                           // Call this error #2.
        //memcpy(txPayload.statusText, "ERROR 02   ", 11);      // Set text to send back to RPi to show error.
        txPayload.ctErrors++;                                   // we have a Tx/ack failure, increment the errors tracking counter.
      } // ACK i.e., bottom of the test to see if we got an ACK back

  } else {
    /* Transmission failed. Report, then fall through and keep trying. */
    /* errorLED (3); <- Let's try skipping the delay this reporting introduces and see what happens */ // Call this error #3.
    digitalWrite(errorLedPin, HIGH);                            // Instead just show LED red to signal an error
    //memcpy(txPayload.statusText, "ERROR 03   ", 11);
    txPayload.ctErrors = txPayload.ctErrors + 1;                // we have a Tx/ack failure, increment the errors tracking counter.
  } // if(report) -i.e., bottom of the transmit success/fail IF-ELSE block


  delay(500);                                                   // Introduce a bit of delay each loop cycle, tho this will mess with timing measurement, so in the end this must go away.
  capacitorMeasurement(&txPayload);                            // Manage and measure the capacitor.

} // data streaming loop



// ==== Capacitor Functions

/*************************************************************************************************
 *    Measure capacitance using Jon's approach. Put the measurement data into the payload
 * structure and return. 
 *    The capacitor under test is connected between chargePin and voltReadPin.
 */
void capacitorMeasurement(TxPayloadStruct * pLoad) {
  startTime = millis();
  pinMode(voltReadPin, INPUT);        // Get ready to measure voltage.
  digitalWrite(chargePin, HIGH);      // Send voltage pulse to cap under test.
  int val = analogRead(voltReadPin);  // Read voltage at point between 'C1' and C-test.

      //Clear everything for next measurement
  digitalWrite(chargePin, LOW);       // Remove voltage from caps.
  pinMode(voltReadPin, OUTPUT);       // ?? - does this discharge C-test to ground??

  elapsedTime= millis() - startTime;  // Capture elapsed time out of curiosity.
  digitalWrite(greenLedPin, LOW);     // For now let's use Green LED on only while CAP is being charged.

      //Calculate and store result
  float capacitance = (float)val * IN_CAP_TO_GND / (float)(MAX_ADC_VALUE - val);

  memcpy(pLoad->statusText, "Measurement", 11);
  pLoad->chargeTime = elapsedTime;
  memcpy(pLoad->units, "pF ", 3);
  pLoad->capacitance = capacitance;
  memcpy(pLoad->statusText, "pF 06/20 a ", 11);
}


void errorLED (int errorNo) {
  digitalWrite(greenLedPin, LOW);           // Turn green LED off.
  digitalWrite(errorLedPin, HIGH);          // Show RED on for a bit before counting out the error number.
  delay(1500);
  digitalWrite(errorLedPin, LOW);
  for (int i=errorNo; i>0; i--) {               // Flash LED to count the error number.
    delay(500);
    digitalWrite(errorLedPin, HIGH);
    delay(500);
    digitalWrite(errorLedPin, LOW);
  }
  delay(500);
  digitalWrite(errorLedPin, HIGH);          // Show RED on for a bit before counting out the error number.
} // errorLED

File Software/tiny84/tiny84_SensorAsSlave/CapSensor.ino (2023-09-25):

// Class: CapSensor - Function Definitions
//=================================================================================================
/*    FOOTNOTES: Note that there are 'footnotes' at the bottom of this file that provide more
 *  detailed info and documentation that I didn't want to clutter up the code with; but which
 *  I am likely to want to remember when I come back to this in 6 months.
 *
 *      09/25/2023: Fixed some logic flow in transitioning between phases which blocked us
 * from getting into phase-3. Also note that the 'inf' cap reading value error was fixed - this 
 * was caused by putting the parameters in the reverse order in the CapSensor capSensor() 
 * declaration.
 *
 *      09/18/2023: Fixed failure to clear _capAccumulator on new reading initiation.
 *
 *      09/17/2023: Added function to retreive the measured value of the sensor's capacitance.
 *
 */
//=================================================================================================


#include "Arduino.h"
#include "CapSensor.h"

//*************************************************************************************************


CapSensor::CapSensor(int chargePin, int voltReadPin) {
      /*      PURPOSE: Constructor. 
       *  Used to set the pin#/reference that the soil capacitor sensor is wired up to. */

  _chargePin = chargePin;                     // Set the pins the sensor leads are wired up to.
  _voltReadPin = voltReadPin; 

  _capacitance = 0;
  _readingAvailable = false;
  _measurePhase = 0;

} // END CapSensor (constructor method)


void CapSensor::setup() {
          /*    PURPOSE: Initilize the sensor to enable readings. */
  pinMode(_chargePin, OUTPUT);
  digitalWrite(_chargePin, LOW);              // Start with 0 volts on charge pin.
  pinMode(_voltReadPin, OUTPUT);
  digitalWrite(_voltReadPin, LOW);            // Start with the analog pin low, 0 volts.

}


void CapSensor::initiateSensorReading() {
          /*    PURPOSE: Change state of the object such that we begin to make a series of 
           *  capacitance readings, which we will average out when done into a 'final' 
           *  reading of the sensor's capacitance value. */

  _capacitance = 0;                           // Clear out prior reading.
  _capAccumulator = 0;
  _readingAvailable = false;
  _ReadingsRemain = NUM_READINGS_TO_AVERAGE;  // Establish number of measurements to average over.
  _nextMeasureMillis = 0;
  _measurePhase = 1;                          // Start the process by moving into Phase-1 of the reading protocol.  
}


bool CapSensor::readingAvailable() {
          /*    PURPOSE: See longish description in capSensor.h. */

  switch(_measurePhase) {
    case 1:                                   // Phase-1: Pulse, Read & Clear.
      if(millis()>_nextMeasureMillis) {       // But only if hard-coded inter-measurement 'rest time' has elapsed.
        pulseAndReadVolts();
        _measurePhase = 2;
      }
      break;

    case 2:                                   // Phase-2: Calculate Capacitance.
      _capAccumulator +=  (float)(_tempVolts * IN_STRAY_CAP_TO_GND) / (float)(MAX_ADC_VALUE - _tempVolts);
      _ReadingsRemain--;
      _nextMeasureMillis = millis() + INTER_MEASUREMENT_DELAY;
      if(_ReadingsRemain) {
        _measurePhase = 1;
      } else {
        _measurePhase = 3;
      }
      break;

    case 3:                                   // Phase-3: Take Average.
      _capacitance = _capAccumulator / NUM_READINGS_TO_AVERAGE;
      _readingAvailable = true;
      _measurePhase = 4;
      break;

    default:                                  // Phase-4: Measurement Available. Don't take any action.
      break;
  }

  return(_readingAvailable);
}


float CapSensor::getCapacitance() {
          /*    PURPOSE: Obtain last read value of the sensor capacitance. */
  return(_capacitance);
}

void CapSensor::pulseAndReadVolts() {
          /*    PURPOSE: Private function. Performs the Phase-1 step of taking one measurement of
           *  the voltage between 'C1' and C-test -> i.e., the sensor's capacitance. */

  pinMode(_voltReadPin, INPUT);         // Get ready to measure voltage.
  digitalWrite(_chargePin, HIGH);       // Send voltage pulse to cap under test.
  _tempVolts = analogRead(_voltReadPin);   // Read voltage at point between 'C1' and C-test.
                                        // -- Clear everything for next measurement --
  digitalWrite(_chargePin, LOW);        // Remove voltage from caps and short C-test to ground.
  pinMode(_voltReadPin, OUTPUT);        // Block C-test & 'C1' short-circut path through voltRead pin in prep for next charge cycle.
}



/**************************************************************************************************
// FOOTNOTES
//*************************************************************************************************

/*   1. PLEASE NOTE: This class will only handle and measure pico-farad level of capacitance.
  The approach to pF scale capacitance measurement is the one described and explained by
  Jonathan Nethercott in a web post back in 2014. I have taken a pdf 'snapshot' of the web page 
  where I got this from. See the file:
  /Reference-and-Instructions/Pico-farad-cap-measurement-with-Arduino.pdf  
*/

/*   2. Also reference documentation in: /Software/Documentation/CapSensor_MeasurementProtocol.odg.
*/

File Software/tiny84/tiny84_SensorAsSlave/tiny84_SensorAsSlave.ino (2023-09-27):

//Moisture Sensor Project - ATTiny84 Code

#define VERSION "SEN_092723"
/*    DESCRIPTION: Arduino sketch to make the ATTiny84 MCU serve as a Slave sensor, with 
 * a Raspberry Pi as the Master - i.e., sensor server.
 *
 *    FOOTNOTES: Note that there are 'footnotes' at the bottom of this file that provide more
 *  detailed info and documentation that I didn't want to clutter up the code with; but which
 *  I am likely to want to remember when I come back to this in 6 months.  : ) 
 *
 *      09/27/2023: No changes to this particular file. One change made in Dispatcher.h 
 * to set the cap reading interval to 15 minutes. And with that change this version is
 * my 'beta' release for testing in a real plant pot to see how it goes.
 *
 *      09/25/2023: Fixed the 'inf' cap reading issue. This was caused by putting the
 * parameters in the reverse order in the CapSensor capSensor() declaration.
 *   
 *      09/15/2023: TC03_TransmitPOC successfully completed. This file has been updated to
 * reflect relevant code used in TC03_TransmitPOC.ino so that we have a sound starting basis
 * for the next iteration of updates.
 *
 *      09/12/2023: First attempt to code up reasonable sensor behavior per the Design Notes in
 *  milestone #12.
 *
 */

// ==== PULL IN REQUIRED LIBRARIES ===============================================================
  #include "HeartBeat.h"
  #include "ErrorFlash.h"
  #include "CapSensor.h"
  #include "RadioComms.h"
  #include "Dispatcher.h"

// ==== PROTOTYPES FOR CLASSES AND FUNCTIONS DEFINED IN THIS SOURCE FILE =========================
// END Prototypes



// ==== PIN REFERENCES. (For ATTiny84 Pin Reference guidance see footnote #1 at bottom of this file.)

    /* Hard-wired LEDs */
  #define LED_GREEN PIN_PA1  // Physical pin #12 The pin that a green led is wired to
  #define LED_ERROR PIN_PB2  // Physical pin #5. The pin that a red led is wired to

    /* Hard-wired pins of nRF24 chip to the ATTiny84 */
  #define CE_PIN PIN_PA2
  #define CSN_PIN PIN_PA3

    /* Hard-wired pins for capacitance measurement. */
  #define CAP_VOLTREAD_PIN A0        // Physical pin#13 - analog 'channel 0' for measuring voltage
  #define CAP_CHARGE_PIN   PIN_PB1   // Physical pin#3 - pin to charge the capacitor - connected to one end of the charging resistor

// END Pin References

// DECLARE GLOBAL VARIABLES =======================================================================

    /* Global Classes (objects) */
  ErrorFlash errorFlash(LED_ERROR);                       // Instantiate an error reporting object.
  HeartBeat heartBeat(LED_GREEN);                         // Instantiate a HeartBeat object.
  RadioComms radio(CE_PIN, CSN_PIN);                      // instantiate my nRF24L01 transceiver wrapper object.
  CapSensor capSensor(CAP_CHARGE_PIN, CAP_VOLTREAD_PIN);  // Instantiate a CapSensor object.
  Dispatcher dispatcher;                                  // Instantiate the Dispatcher object.

// END Declare Global Variables



// ==== SETUP PROCEDURE===========================================================================
void setup() {

  heartBeat.begin();                            // Start the heartbeat LED. Keep it lit for entire setup() process.
  errorFlash.begin();                           // Start the error reporting-out-by-flashing-LED process.
  capSensor.setup();
  if (!radio.setup()) errorFlash.setError(9);   // If radio chip isn't there, set errorID 9.
  dispatcher.begin();

} // END setup()



// ==== Processor Running Loop
/*************************************************************************************************
 *    Using the 'non-blocking' classes/objects I've created, go into the standard Arduino 
 * infinitely running loop, continuously calling the various dispatch and update functions to
 * share processor time between the various tasks.
 */
void loop() {

  dispatcher.dispatch();
  heartBeat.update();
  errorFlash.update();

} // END loop()



//*************************************************************************************************
// FOOTNOTES
//*************************************************************************************************

   /*   1. When compiling you might see this warning: #warning "This is the CLOCKWISE pin 
      mapping - make sure you're using the pinout diagram with the pins in clockwise order." 
        As long as all pin references are in the SpenceKonde attiny core recommended form then ignore
      the warning. In fact, no matter which core variant you use you'll get a warning either way.
      Pin references should be of the form: "PIN_PA#" or PIN_PB#," for digital pins. For the 
      analog pins use the analog channel number as shown on the pinout diagram. E.g., use 
      'A7' for ADC7, physical pin #6; 'A0' for ADC0, physical pin 13. As long as you use this 
      pin referencing system the clock/counter-clock-wise pin ordering thing is irrelevant.
    */

   /*   2. Notes on return value from [bool report = radio.write(&txPayload, sizeof(txPayload));]
      FROM the RF24.h file, documentation on the return value of this function: Returns`true` 
      if the payload was delivered successfully and an acknowledgement (ACK packet) was received. 
      If auto-ack is disabled, then any attempt to transmit will also return true (even if the 
      payload was not received). Returns 'false` if the payload was sent but was not 
      acknowledged with an ACK packet. This condition can only be reported if the auto-ack 
      feature is on. 
    */

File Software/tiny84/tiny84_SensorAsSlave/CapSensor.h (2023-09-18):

// Class: CapSensor - Class Definition
//=================================================================================================

#ifndef CapSensor_h
#define CapSensor_h

#include "Arduino.h"

/************************************************************************************************
*
*    PURPOSE: Manages the soil sensor capacitor.
*
*    USAGE:
*    1. CapSensor object must be created (declared) using the pin# reference that the sensor
*  wired up to.
*    2. You call the .begin() method to initiate the error LED cycle - do this first, even 
*  when no error condition yet exists. Typically you'll do this in the sketch's setup() 
*  function, but could be done anywhere.
*    3. You must call the .update() method as part of the sktech's loop() function for the 
*  error LED to be responsive to a reported error.
*    4. To report an error, call the setError() function.
*
*    NOTE:
*    1. By design, this class is non-blocking.
*/


#define IN_STRAY_CAP_TO_GND 24.48     // Stray capacitance, used as 'C1' in schematic. Adjust this value to calibrate the measurement.
#define MAX_ADC_VALUE 1023            // Fixed by the microprocessor model & specs. This for ATTiny84.
#define NUM_READINGS_TO_AVERAGE 10    // How many readings to take and compute a 'final' average reading for.
#define INTER_MEASUREMENT_DELAY 300   // Minimum number of milliseconds to wait between successive cap readings to accumulate an average.

class CapSensor {

  private:
    int _chargePin;                   // Pin number 1st lead of cap is wired to.
    int _voltReadPin;                 // Pin number 2nd lead of cap is wired to.
    short int _measurePhase;          // Were we are in the measure protocol 0:No Measurement. 1:Pluse, Read & Clear. 2: Calculate. 3: Take Average. 4: Measurement Available.
    float _capacitance;               // Measured capacitance value.
    bool _readingAvailable;           // Will be TRUE if a sensor capacitance reading has completed.
    short int _ReadingsRemain;        // The number of readings remaining in the total number we're averaging over.
    float _capAccumulator;            // Will accumulate multiple cap readings so we can take an average for the final value.
    unsigned long _nextMeasureMillis; // Wait until at least this time to take another reading.
    int _tempVolts;                   // Stores voltage reading between Phase-1 and Phase-2.


  public:

          /*    PURPOSE: Constructor. 
       *  Used to set the pin#/reference that the sensing capacitor is wired up to. */
    CapSensor(int chargePin, int voltReadPin);

          /*    PURPOSE: Initilize the sensor to enable readings. */
    void setup();

          /*    PURPOSE: Change state of the object such that we begin to make a series of 
           *  capacitance readings, which we will average out when done into a 'final' 
           *  reading of the sensor's capacitance value. */
    void initiateSensorReading();

          /*    PURPOSE: Serves two purposes - One, serves as the 'update' function for
          * an ongoing cap reading request. That is, it's going to cause a bit of work 
          * to be done on making a reading, then return control back to the loop() so
          * we don't 'block' the processor. Secondly, once a reading process has been
          * completed, and is now now available, this will return TRUE so that the
          * calling program will know it can get the reading data.. It will return FALSE
          * while the reading process is ongoing. To get a new reading, and not simply
          * return an old, prior, reading be sure to call makeReading() before testing
          * this. For a somewhat graphical view of the logic of this function see:
          * /Software/Documentation/CapSensor_MeasurementProtocol.odg. */
    bool readingAvailable();


          /*    PURPOSE: Obtain last read value of the sensor capacitance. */
    float getCapacitance();


  private:
    void pulseAndReadVolts();

};
#endif

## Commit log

2023-06-21 Initial commit. At Milestone 10.
    [PinMappings.ods, SensorCircuit_On-perfBoard.fzz]
2023-07-08 Milestone 12. Completed initial test of heartbeat and ErrorFlash. ErrorFlash needs a touch more work.
    [CapSensor.h, CapSensor.ino, Dispatcher.ino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]
2023-07-08 Milestone 12. HeartBeat and ErrorFlash passed testing. Ready to work on cap measurement object with Dispatcher.
    [Dispatcher.ino, ErrorFlash.ino]
2023-07-09 Milestone 12. Completed Test Case 01 and some add'l documentation.
2023-07-18 TC02_CapClass. Commit just prior to initiating work on test case.
2023-09-14 TC03_TransmitPOC. Commit just prior to initiating work on test case.
2023-09-25 WIP save to go back to earlier commit to work on Issue #1.
    [Dispatcher.ino, RadioComms.h, RadioComms.ino]
2023-09-26 WIP Issue-1: Found trigger for issue. Still need to do final clean up for it.
    [RadioComms.h, RadioComms.ino]
